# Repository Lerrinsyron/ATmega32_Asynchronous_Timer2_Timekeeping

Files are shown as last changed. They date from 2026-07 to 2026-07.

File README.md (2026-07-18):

ATmega32 Asynchronous Timer2 Timekeeping

CT 321 — Group 13 

Low-power real-time clock using ATmega32 Timer2 in asynchronous mode, driven by a 32.768 kHz watch crystal on TOSC1/TOSC2. The CPU sleeps between timer events; Timer2 keeps running and wakes the CPU exactly once per second.

Build
```bash
cd firmware

# Real hardware
avr-gcc -mmcu=atmega32 -DF_CPU=8000000UL -Os -I/usr/avr/include \
  -o hex/firmware.elf src/main.c
avr-objcopy -O ihex -R .eeprom hex/firmware.elf hex/firmware.hex

# SimulIDE
avr-gcc -mmcu=atmega32 -DF_CPU=8000000UL -DSIMULIDE_MODE -Os -I/usr/avr/include \
  -o hex/firmware_simulide.elf src/main.c
avr-objcopy -O ihex -R .eeprom hex/firmware_simulide.elf hex/firmware_simulide.hex
```

If `/usr/avr/include` doesn't exist on your machine, run `find /usr -name "io.h" | grep avr` to find your avr-libc path.

SimulIDE

Load hex/firmware_simulide.hex into the ATmega32. Set Freq to `8000000` and Serial Monitor baud to `9600`.

> ⚠️ Known limitation: SimulIDE cannot model the external 32.768 kHz crystal on TOSC1/TOSC2. The SIMULIDE_MODE   build uses an internal-clock CTC fallback to produce the same 1-second tick. The KiCad design remains correct for real hardware.

Common Issues

Garbage output on serial monitor baud rate mismatch. Confirm SimulIDE Serial Monitor is set to 9600, not 4800.

"SLEEP instruction not fully implemented" warning expected. SimulIDE does not model power-save sleep. Ignore it; everything else works correctly.

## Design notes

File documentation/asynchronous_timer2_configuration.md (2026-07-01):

# SimulIDE Simulator Limitation — Asynchronous Timer2 Oscillator

## Limitation Description

SimulIDE 1.1.0 does not fully model the external crystal oscillator circuit
connected to the TOSC1 (PC6) and TOSC2 (PC7) pins of the ATmega32. When the
`AS2` bit in the `ASSR` register is set to 1 and an external 32.768 kHz
crystal is wired to TOSC1/TOSC2, SimulIDE does not drive Timer2 from that
crystal. Timer2 either does not run or behaves incorrectly in simulation.

This is a known limitation of SimulIDE's AVR peripheral model — the
asynchronous clock domain for Timer2 is not implemented.

Additionally, SimulIDE prints the following warning when the firmware executes
a sleep instruction:

    Warning: AVR SLEEP instruction not Fully implemented
    eMcu::sleep: Sleeping

This confirms that power-save sleep mode (SLEEP_MODE_PWR_SAVE), which keeps
Timer2 running while the CPU halts, is also not fully modelled. In simulation
the CPU continues executing rather than entering a true sleep state.

---

## Impact on Simulation

| Feature | Real hardware | SimulIDE behaviour |
|---|---|---|
| Timer2 async crystal clock | Runs from 32.768 kHz TOSC | Not modelled |
| 1-second overflow interrupt | Exact, zero error | Not generated |
| Power-save sleep mode | CPU halts, Timer2 runs | CPU does not halt |
| Wake on Timer2 overflow | Works correctly | Not triggered |

---

## Workaround Implemented

As permitted by the project specification, an equivalent Timer2 configuration
using the internal CPU clock was implemented for simulation. This is activated
by compiling the firmware with the `-DSIMULIDE_MODE` preprocessor flag:

```bash
avr-gcc -mmcu=atmega32 -DF_CPU=8000000UL -DSIMULIDE_MODE -Os \
  -I/usr/avr/include \
  -o hex/firmware_simulide.elf src/main.c

avr-objcopy -O ihex -R .eeprom hex/firmware_simulide.elf firmware_simulide.hex
```

### Fallback Timer2 Configuration

In SimulIDE mode, Timer2 is configured in CTC (Clear Timer on Compare) mode
using the internal 8 MHz CPU clock:

```c
TCCR2 = (1 << WGM21)                           /* CTC mode            */
      | (1 << CS22) | (1 << CS21) | (1 << CS20); /* prescaler /1024   */
OCR2  = 77;
TIMSK |= (1 << OCIE2);   /* compare-match interrupt ~100 times/second */
```

The ISR accumulates 100 compare-match events before incrementing the clock,
producing a software-defined 1-second period with ~0.16% timing error.

### What Remains Unchanged in Simulation

All timekeeping logic, alarm comparison, LED toggling, buzzer activation,
button handling, and USART output behave identically in both the real hardware
and SimulIDE builds. Only the clock source differs.

---

## KiCad Design Correctness

Despite the simulator limitation, the KiCad schematic and PCB layout reflect
the correct real-hardware design:

- 32.768 kHz watch crystal connected between TOSC1 (PC6) and TOSC2 (PC7)
- Two 22 pF NP0/C0G load capacitors from each crystal pin to GND
- Crystal placed close to the MCU with short traces
- TOSC traces routed away from switching outputs

The SimulIDE workaround is purely a firmware compile-time switch and does not
affect the hardware design in any way.

---

## Sleep Mode Documentation

Since SimulIDE does not implement power-save sleep mode, the low-power
behaviour is documented here rather than demonstrated in simulation.

In real hardware operation:

1. After each Timer2 overflow ISR completes, `main()` calls `enter_sleep()`
2. The CPU enters SLEEP_MODE_PWR_SAVE — halting the CPU clock and most peripherals
3. Timer2 and its external crystal oscillator continue running unaffected
4. After exactly 1 second the next Timer2 overflow fires, waking the CPU
5. The ISR runs, updates the clock, and `main()` resumes briefly before sleeping again

In this mode the ATmega32 current consumption drops from ~5 mA active to
roughly 1–2 µA, allowing a coin cell battery to power the timekeeping system
for months.

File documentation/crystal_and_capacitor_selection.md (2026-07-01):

# Crystal and Load Capacitor Selection

## 32.768 kHz Watch Crystal

The ATmega32 Timer2 asynchronous oscillator requires an external low-frequency
crystal connected to TOSC1 (PC6) and TOSC2 (PC7). The standard choice for
timekeeping applications is a 32.768 kHz watch crystal.

### Why 32.768 kHz?

32.768 kHz = 2^15 Hz

This frequency is a power of two. Dividing it by 2 fifteen times gives exactly
1 Hz — one tick per second. This makes it the industry standard for all
real-time clock (RTC) applications including wristwatches, alarm clocks, and
embedded timekeeping systems.

In this project the division is handled by Timer2's prescaler and 8-bit
overflow rather than a binary divider chain, but the principle is the same.

### Selected Crystal

| Parameter | Value |
|---|---|
| Frequency | 32.768 kHz |
| Package | Cylindrical through-hole (2-pin), e.g. MC-306 or equivalent |
| Frequency tolerance | ±20 ppm typical |
| Load capacitance (CL) | 6 pF or 12.5 pF (see datasheet) |
| ESR (max) | 70 kΩ typical |
| Operating temperature | -10°C to +60°C |
| Application | TOSC1/TOSC2 on ATmega32 |

Common equivalent parts: Epson FC-135, Abracon AB38T, or any standard
32.768 kHz watch crystal with CL of 6–12.5 pF.

---

## Load Capacitors

Every crystal oscillator requires two load capacitors — one from each crystal
pin to ground. These capacitors are part of the oscillator feedback network.
Without them the crystal will not oscillate reliably or at all.

### How to Calculate Load Capacitor Value

The crystal datasheet specifies a load capacitance CL. The two external
capacitors (C1 and C2) appear in series from the oscillator's perspective,
so the formula is:

    CL = (C1 × C2) / (C1 + C2) + Cstray

Where Cstray is the parasitic capacitance of the PCB traces and MCU pins,
typically 2–5 pF.

For a symmetric design where C1 = C2 = C:

    CL = C/2 + Cstray
    C  = 2 × (CL - Cstray)

### Calculation for This Project

Assuming CL = 12.5 pF and Cstray = 2 pF:

    C = 2 × (12.5 - 2)
    C = 2 × 10.5
    C = 21 pF

The nearest standard capacitor value is **22 pF**.

For a crystal with CL = 6 pF:

    C = 2 × (6 - 2) = 8 pF → use 8.2 pF standard value

### Selected Load Capacitors

| Parameter | Value |
|---|---|
| Value | 22 pF (or 8.2 pF for CL=6 pF crystal) |
| Type | NP0 / C0G ceramic (low drift) |
| Voltage rating | 10 V or higher |
| Quantity | 2 (one per crystal pin) |
| Placement | As close as possible to TOSC1/TOSC2 pins on PCB |

NP0/C0G type capacitors are mandatory for oscillator circuits — they have
near-zero temperature coefficient, meaning their value does not drift with
temperature. X7R or Y5V types drift significantly and will cause the clock
to run fast or slow as temperature changes.

---

## PCB Placement Requirements

| Requirement | Reason |
|---|---|
| Place crystal within 5 mm of PC6/PC7 pins | Long traces add parasitic inductance and capacitance |
| Keep TOSC traces short and direct | Reduces noise pickup |
| Route TOSC traces away from switching signals (PB0, PB1, TXD) | Switching edges can couple into the high-impedance oscillator circuit |
| Do not place vias under crystal | Vias add stray capacitance |
| Connect load capacitor grounds to a local ground pour | Reduces ground impedance at oscillator frequency |

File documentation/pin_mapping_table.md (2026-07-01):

# Pin Mapping Table

## TOSC1 / TOSC2 — Asynchronous Timer2 Oscillator Pins

| Pin Name | ATmega32 Pin No. | Port / GPIO | Direction | Connected To | Description |
|---|---|---|---|---|---|
| TOSC1 | 29 | PC6 | Input | 32.768 kHz crystal pin 1 | Timer2 external oscillator input. Receives the crystal clock signal. |
| TOSC2 | 28 | PC7 | Output | 32.768 kHz crystal pin 2 | Timer2 external oscillator output. Completes the crystal feedback loop. |

## Notes

- When `AS2` bit in the `ASSR` register is set to 1, PC6 and PC7 are **disconnected from Port C** and dedicated exclusively to the Timer2 oscillator circuit. They cannot be used as general-purpose GPIO while asynchronous mode is active.
- The 32.768 kHz watch crystal must be connected directly between TOSC1 and TOSC2 with load capacitors from each pin to GND.
- TOSC1/TOSC2 traces must be kept short on the PCB and routed away from switching signals to avoid noise coupling into the oscillator.

## Full Project Pin Mapping

| ATmega32 Pin | Pin No. | Function | Direction | Connected To | Notes |
|---|---|---|---|---|---|
| PC6 / TOSC1 | 29 | Timer2 oscillator input | Input | 32.768 kHz crystal | Do not use as GPIO when AS2=1 |
| PC7 / TOSC2 | 28 | Timer2 oscillator output | Output | 32.768 kHz crystal | Do not use as GPIO when AS2=1 |
| PB0 | 1 | Wake-up LED | Output | LED + 330 Ω resistor | Toggles every 10 seconds |
| PB1 | 2 | Alarm buzzer | Output | Buzzer | Activates when alarm time is reached |
| PA0 | 40 | Reset button | Input | Push button to GND | Active LOW, internal pull-up enabled |
| PA1 | 39 | Set alarm button | Input | Push button to GND | Active LOW, internal pull-up enabled |
| PA2 | 38 | Increment button | Input | Push button to GND | Active LOW, internal pull-up enabled |
| PD1 / TXD | 15 | USART transmit | Output | Serial terminal RX | 4800 baud, 8N1 |
| VCC | 10 | Power supply | Power | 5 V rail | Main digital power |
| AVCC | 11 | Analog power supply | Power | 5 V rail | Required even without ADC use |
| GND | 11, 31 | Ground | Power | Ground | Both GND pins must be connected |
| RESET | 9 | Master reset | Input | 5 V rail via pull-up | Active LOW — held HIGH for normal operation |

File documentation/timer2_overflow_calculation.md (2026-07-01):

# Timer2 Prescaler and Overflow Period Calculation

## Overview

Timer2 in asynchronous mode is clocked directly from the 32.768 kHz watch
crystal via TOSC1. The goal is to configure Timer2 so that its overflow
interrupt fires exactly once per second, giving a 1 Hz timekeeping base.

---

## Timer2 Characteristics

| Property | Value |
|---|---|
| Timer width | 8-bit (counts 0 to 255) |
| Clock source | External 32.768 kHz crystal (AS2=1) |
| Overflow point  | After 256 counts (0xFF → 0x00) |
| Available prescalers | /1, /8, /32, /64, /128, /256, /1024 |

---

## Derivation

The timer overflow period is:

    T_overflow = (Prescaler × 256) / f_TOSC

We need T_overflow = 1 second and f_TOSC = 32768 Hz.

Rearranging for the prescaler:

    Prescaler = (T_overflow × f_TOSC) / 256
    Prescaler = (1 × 32768) / 256
    Prescaler = 128

**Prescaler = 128** is an available option (CS2[2:0] = 0b101). ✓

---

## Verification

    f_TOSC      = 32768 Hz
    Prescaler   = 128
    Timer ticks per second = 32768 / 128 = 256 ticks/second

    Timer2 is 8-bit → overflows after 256 counts

    T_overflow  = 256 / 256 = 1.000 second ✓

Timer2 generates exactly one overflow interrupt per second with zero error.
This is the key advantage of the 32.768 kHz frequency — it divides cleanly
by 128 × 256 = 32768 with no remainder.

---

## Register Configuration

```c
/* Enable asynchronous mode — Timer2 clocked from TOSC1 crystal */
ASSR |= (1 << AS2);

/* Set prescaler /128: CS22=1, CS21=0, CS20=1 */
TCCR2 = (1 << CS22) | (1 << CS20);

/* Wait for async registers to synchronise (mandatory per datasheet) */
while (ASSR & ((1 << TCN2UB) | (1 << OCR2UB) | (1 << TCR2UB)));

/* Enable Timer2 overflow interrupt */
TIMSK |= (1 << TOIE2);
```

### CS2 Prescaler Bit Table (ATmega32 Datasheet)

| CS22 | CS21 | CS20 | Prescaler |
|---|---|---|---|
| 0 | 0 | 0 | Timer stopped |
| 0 | 0 | 1 | /1 |
| 0 | 1 | 0 | /8 |
| 0 | 1 | 1 | /32 |
| 1 | 0 | 0 | /64 |
| 1 | 0 | 1 | /128 ← selected |
| 1 | 1 | 0 | /256 |
| 1 | 1 | 1 | /1024 |

---

## SimulIDE Fallback Calculation

SimulIDE cannot simulate the external 32.768 kHz crystal. In simulation,
Timer2 is reconfigured in CTC (Clear Timer on Compare) mode using the
internal 8 MHz CPU clock to approximate 1-second ticks in software.

    f_CPU       = 8,000,000 Hz
    Prescaler   = 1024
    OCR2        = 77  (compare match value)

    f_compare   = f_CPU / (Prescaler × (OCR2 + 1))
    f_compare   = 8,000,000 / (1024 × 78)
    f_compare   = 8,000,000 / 79,872
    f_compare   ≈ 100.16 Hz

The ISR accumulates 100 compare-match events in a software counter
(g_tick_count) before incrementing the clock — giving a period of:

    T_second    = 100 / 100.16 ≈ 0.9984 seconds

Error ≈ 0.16% — acceptable for simulation demonstration purposes.
This fallback is activated by compiling with -DSIMULIDE_MODE and does
not affect the real hardware configuration.

---

## Summary

| Parameter | Real hardware | SimulIDE fallback |
|---|---|---|
| Clock source | 32.768 kHz crystal | 8 MHz internal RC |
| Timer mode | Normal (overflow)  | CTC (compare match)  |
| Prescaler | /128 | /1024 |
| Overflow/compare | 256 counts | OCR2 = 77 |
| ISR rate | 1 Hz exactly | ~100 Hz |
| Software accumulator | not needed | 100 ticks = 1 second |
| Timing error | 0% | ~0.16% |

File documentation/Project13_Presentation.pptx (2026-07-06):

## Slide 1

ATmega32 MCU

8 MHz internal RC

32.768 kHz Crystal

TOSC1 / TOSC2

Power-Save Sleep

µA-level idle

Timer2 Async

1-second ISR

Bare-Metal C

AVR-GCC firmware

Project 13

Asynchronous Timer2
Low-Power Timekeeping

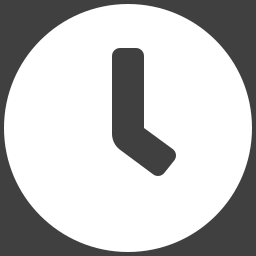
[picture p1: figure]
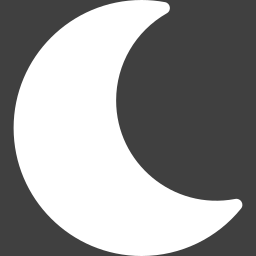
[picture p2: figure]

ATmega32 Microcontroller · 32.768 kHz Watch Crystal · Power-Save Sleep Mode

SimulIDE Simulation · KiCad Schematic & PCB · MPLAB for VS Code

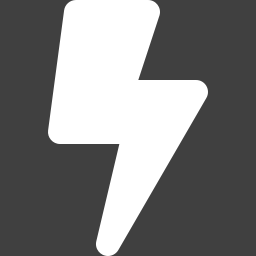
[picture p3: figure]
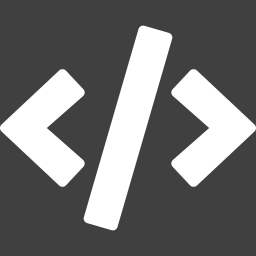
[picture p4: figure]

Embedded Systems

Computer Engineering

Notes: Introduce the project: low-power timekeeping using ATmega32 Timer2 in asynchronous mode with a 32.768 kHz watch crystal. The big idea is that Timer2 can run from its own independent clock while the CPU sleeps.

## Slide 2

The Problem & The Solution

The Problem

- Battery devices need to keep time 24/7
- CPU at 8 MHz draws 8–12 mA constantly
- Software timers drift when CPU is busy or interrupted
- Hours of battery life instead of months

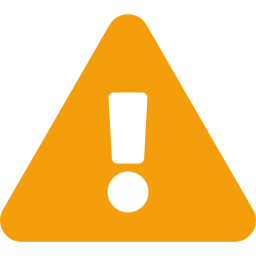
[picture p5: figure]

The Solution

- Timer2 runs from a 32.768 kHz watch crystal
- Crystal is completely independent from the CPU clock
- CPU sleeps in Power-Save mode — wakes once per second
- Average current drops to ~100 µA → months of battery life

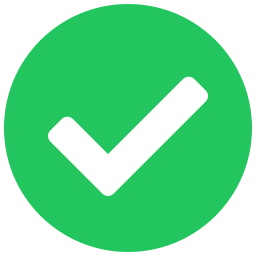
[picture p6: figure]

→

32.768 kHz crystal = 2¹⁵ Hz → divides to exactly 1 Hz with no rounding error

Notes: The core insight: every battery-powered clock needs a way to keep time while the main processor sleeps. The 32.768 kHz crystal is used because it's 2^15 Hz — binary division to exactly 1 Hz with zero rounding error. Timer2 can be wired to this crystal independently of the CPU clock.

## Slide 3

How Timer2 Async Mode Works

CPU Clock Domain

8 MHz internal RC
Drives CPU, Timer0, Timer1
Stops during Power-Save sleep

Timer2 Async Domain

32.768 kHz TOSC crystal
Runs ONLY Timer2
Never stops — even while CPU sleeps

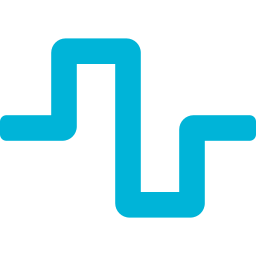
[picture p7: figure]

Power-Save Sleep

CPU halts
Synchronous clocks stop
Only async Timer2 stays alive

≠

→

Key register: ASSR |= (1 << AS2) — switches Timer2 from CPU clock to TOSC1/TOSC2 pins

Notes: Timer0 and Timer1 always use the CPU clock. Timer2 is special — setting AS2 in ASSR disconnects it from the CPU clock and connects it to whatever crystal you put on TOSC1/TOSC2 pins. This is the hardware feature at the heart of the project.

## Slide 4

System Architecture

32.768 kHz
Watch Crystal
(TOSC1/TOSC2)

async clk

Timer2
Async Mode
÷128 → 1s OVF

ISR

ATmega32 CPU
8 MHz internal RC
(Power-Save sleep)

PB0 → LED (330Ω) · Wake every 10s

PB1 → Buzzer · Alarm for 3s

Buttons (active-LOW + internal pull-ups)
PA0: Reset time · PA1: Set alarm mode · PA2: Increment field

Power-Save Sleep Cycle

PD1 → SerialTerm @ 9600 baud 8N1
TIME: HH:MM:SS · ALRM: HH:MM:SS · MODE: LOW POWER

← repeats every second (CPU active <1ms out of 1000ms)

CPU wakes
(ISR fires)

Update clock
Check alarm
Toggle LED

Set flag
Return

Main loop
Refreshes display

enter_sleep()
CPU halts

1 second
passes

→

→

→

→

→

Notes: Walk through the system architecture. Key point: the 32.768 kHz crystal feeds ONLY Timer2 via TOSC1/TOSC2 pins. The CPU wakes once per second, does its work in under a millisecond, then sleeps again. This is what makes the system low-power.

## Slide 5

Timer2 Timing Calculation

32768

Hz

= 2¹⁵

Only frequency that divides to exactly 1 Hz using binary prescalers alone

Crystal frequency

f_TOSC = 32,768 Hz

Timer2 is 8-bit → counts 0–255

256 counts per overflow

Prescaler needed

N = 32768 ÷ 256 = 128

TCCR2 bits CS2[2:0]

= 0b101 (prescaler /128)

Overflow period

T = (256 × 128) ÷ 32768 = 1.000 s ✓

Load caps C1 & C2 = 12 pF match the crystal's specified load capacitance for stable oscillation

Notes: Walk through the math. Timer2 has 256 counts before overflow. 32768 ÷ 256 = 128 exactly. So prescaler /128 gives exactly one overflow per second with no rounding error ever. The load capacitors must match the crystal's datasheet spec (typically 7-12 pF for watch crystals).

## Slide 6

KiCad Schematic & PCB Design

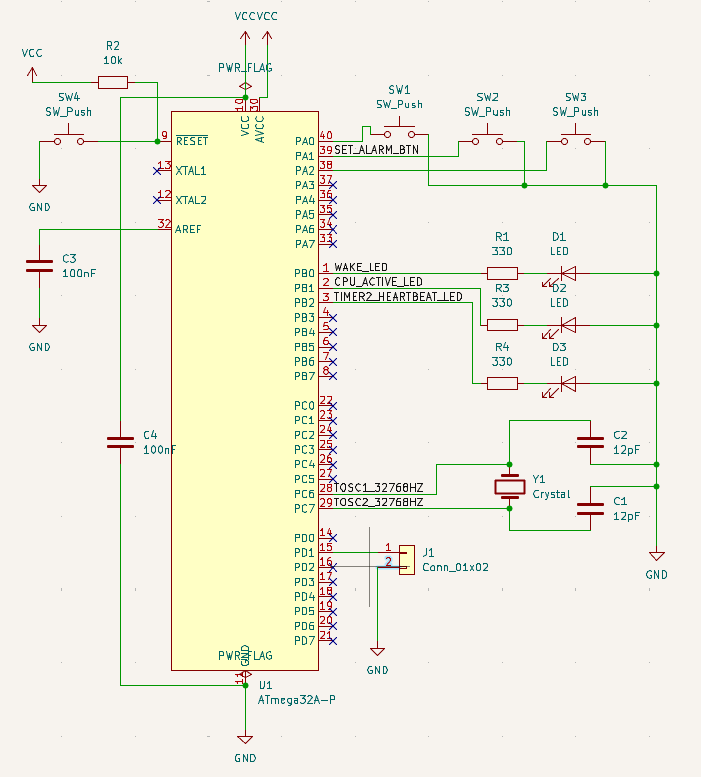
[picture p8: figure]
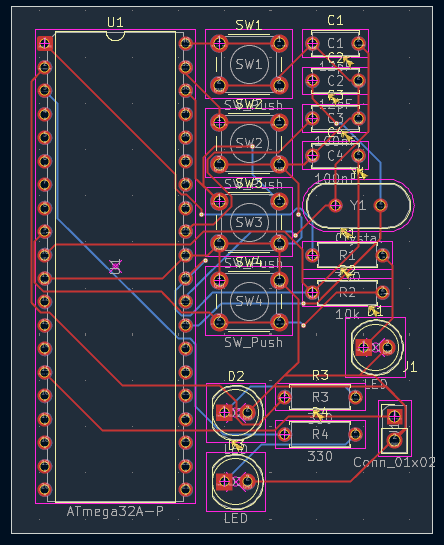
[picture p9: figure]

✔ C1 & C2 (12 pF) immediately adjacent to crystal — short GND routes

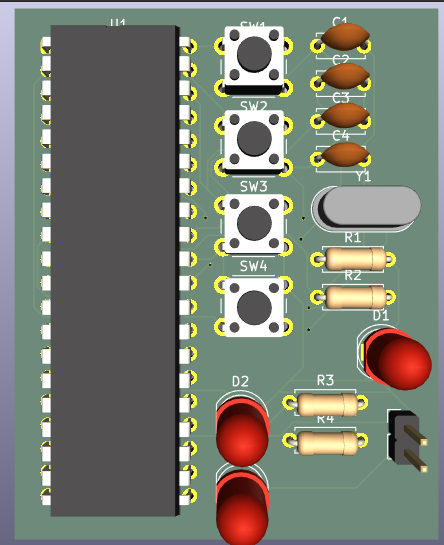
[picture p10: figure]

✔ Y1 placed as close as possible to PC6/PC7 — minimises TOSC trace length

Figure 3.1 — KiCad Schematic

✔ TOSC1/TOSC2 traces routed away from LED switching outputs

Figure 3.4 — KiCad 3D PCB Render

ERC: 0 errors · DRC: 0 violations · Gerber files generated

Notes: The schematic has all five required net labels: TOSC1_32768HZ, TOSC2_32768HZ, WAKE_LED, ALARM_BUZZER, SET_ALARM_BTN. The PCB follows the crystal placement rules: crystal close to TOSC pins, load caps adjacent, TOSC traces away from switching outputs.

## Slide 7

Firmware: The Heart — Timer2 ISR

ISR(TIMER2_OVF_vect) { g_seconds++;
// roll over at 60/60/24
if (g_seconds % 10 == 0)
PORTB ^= (1<<PB0); // toggle LED
if (time == alarm_time) {
PORTB |= (1<<PB1); // buzzer ON
g_buzz_countdown = 3;
}
g_time_updated = true;
}

Runs exactly once per second — no drift

✓

Increments seconds → minutes → hours with midnight rollover

✓

Toggles PB0 (LED) every WAKEUP_INTERVAL=10 seconds

✓

Activates buzzer (PB1) for ALARM_BUZZ_DURATION=3s on alarm match

✓

Sets g_time_updated flag — wakes main loop to refresh serial output

✓

All variables volatile — modified in ISR, read in main

!

cli()/sei() around multi-byte reads to prevent torn reads

!

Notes: The ISR is the heart of the firmware. It fires exactly once per second (on real hardware). Inside it: increment the clock, check for 10-second LED toggle, check alarm condition, manage buzzer countdown, then set the flag that wakes the main loop to print to serial.

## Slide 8

Two Critical Details

Async Register Sync (MANDATORY)

Timer2 registers cross two clock domains.
After writing, you MUST wait for ASSR busy flags to clear:

while (ASSR & (TCN2UB|OCR2UB|TCR2UB));

Skipping this loop silently corrupts
Timer2 configuration — no error, no warning, just a timer that doesn't work correctly. The ATmega32 datasheet mandates this wait.

Sleep Mode Selection

SLEEP_MODE_PWR_SAVE

Stops CPU + sync clocks.
Async Timer2 keeps running from crystal.

SLEEP_MODE_IDLE

Stops only CPU.
Keeps sync clocks — needed for CTC fallback.

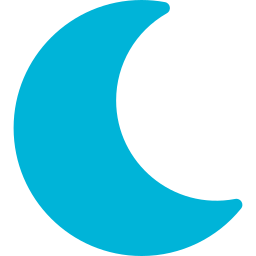
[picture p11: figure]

Real hardware

SimulIDE fallback

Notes: Two non-obvious implementation details. First: the ASSR busy flags MUST be waited on after any Timer2 register write — skipping this is a silent bug. Second: Power-Save stops the synchronous clock, which is perfect for the real hardware path but breaks the SimulIDE fallback that uses the synchronous clock for Timer2.

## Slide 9

SimulIDE: Limitation & Fallback Solution

SimulIDE Cannot Model TOSC

Without SIMULIDE_MODE flag:
• Timer2 waits for crystal that never starts
• ASSR busy flags never clear
• enter_sleep() → CPU parks permanently
• Serial output stops after one line

SIMULIDE_MODE Fallback

Compile with: make simulide
• Timer2 → CTC mode, internal 8 MHz clock
• OCR2=77, /1024 → ~100 ticks/second
• ISR accumulates 100 ticks = 1 second
• SLEEP_MODE_IDLE keeps sync clock alive

What's different vs. what stays the same

Timer2 clock source

Real Hardware

32.768 kHz TOSC crystal

SimulIDE Fallback

8 MHz internal CPU clock

Timer2 mode

Normal (overflow)

CTC (compare match)

Sleep mode

All application logic (clock/alarm/LED/buzzer/USART/buttons)

SLEEP_MODE_PWR_SAVE

✓ IDENTICAL

SLEEP_MODE_IDLE

✓ IDENTICAL

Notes: Two separate bugs that had to be understood and fixed for the SimulIDE simulation to work. The firmware has two compile-time paths. Everything the user sees — clock counting, alarm, LED, buzzer, buttons — is identical. Only the clock source and sleep depth change.

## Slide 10

Simulation Results

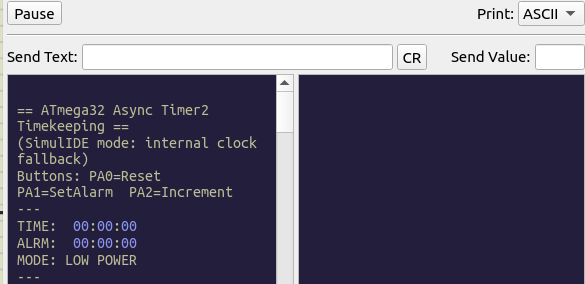
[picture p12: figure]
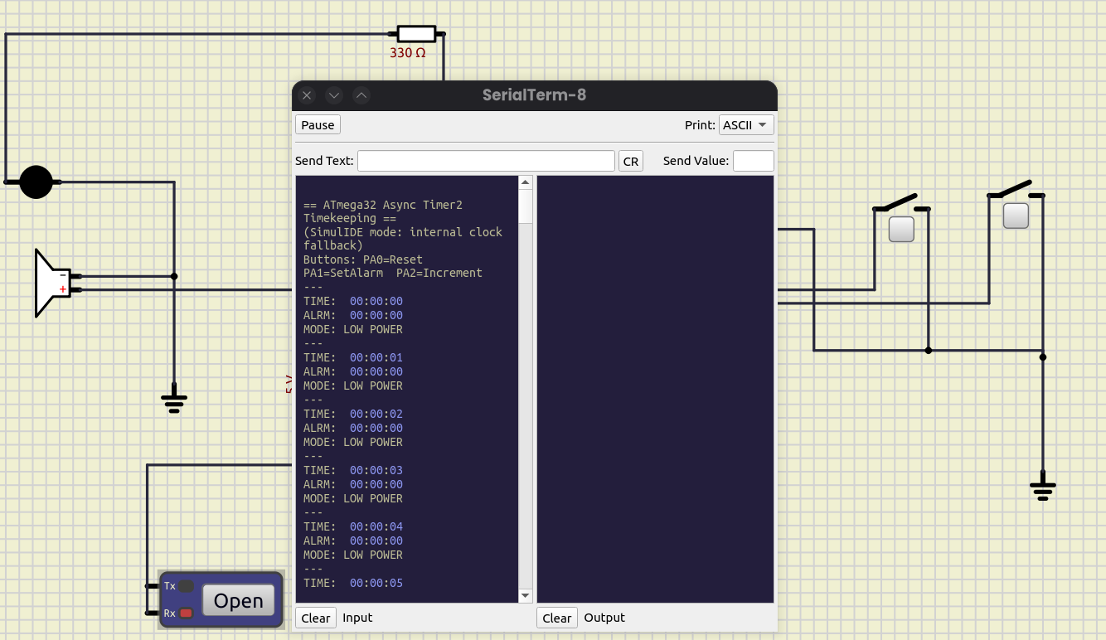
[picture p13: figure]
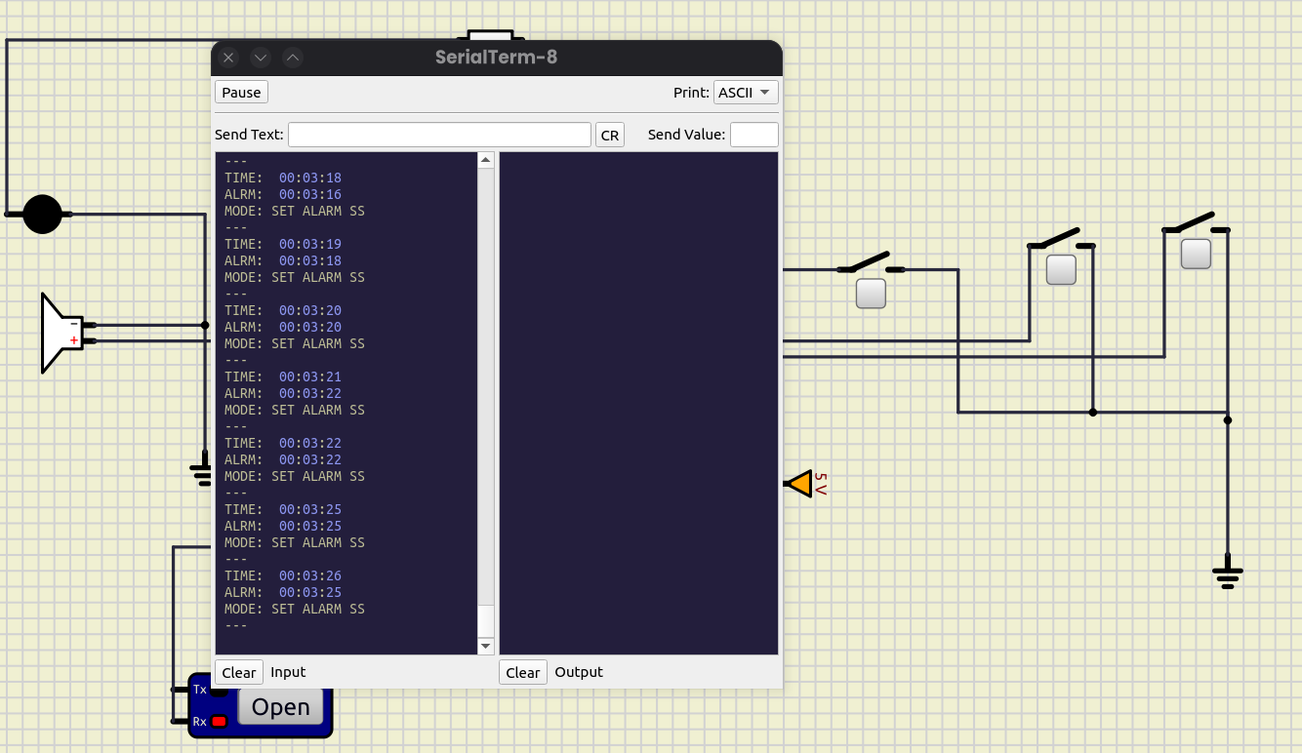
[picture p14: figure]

TC-04: SET ALARM mode

Alarm set and buzzer fires

TC-01: Boot + 00:00:00

System initialises correctly

TC-02: Seconds increment

Timer2 counting in real time

✓ PASS

TC-01
Boot / Reset

✓ PASS

TC-02
Clock counts

✓ PASS

TC-03
LED heartbeat

✓ PASS

TC-04
Alarm / buzzer

✓ PASS

TC-05
Reset button

✓ PASS

TC-06
Sleep (docs)

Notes: All six test cases passed. TC-06 is documented rather than a traditional pass/fail since SimulIDE doesn't fully model sleep modes — the workaround (SLEEP_MODE_IDLE in simulation) is explained and justified.

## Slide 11

Key Learning Outcomes

Async Peripheral Operation

Timer2 is unique among ATmega32 timers — only it can be decoupled from the CPU clock via TOSC pins. This decoupling enables hardware timekeeping independent of CPU state.

01

Clock Domain Crossing

Registers that cross clock domains require explicit synchronisation. The ASSR busy-flag wait loop is mandatory; skipping it produces a silent, hard-to-diagnose bug.

02

Sleep Mode Mechanics

SLEEP_MODE_PWR_SAVE stops all synchronous clocks but preserves the async Timer2 domain. Pairing it with a synchronous-clocked Timer2 (fallback) creates a deadlock — the correct fix is SLEEP_MODE_IDLE.

03

USART Baud Rate Sensitivity

UBRR is computed from F_CPU. A MCU clock mismatch between firmware and simulator (16 MHz vs 8 MHz) garbles every byte. Matching both values is the first debug step for garbled serial.

04

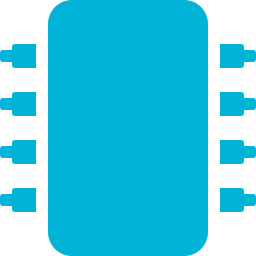
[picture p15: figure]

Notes: Four takeaways from the project. Most important: Timer2's unique async capability is the enabler for everything else. The register sync and sleep mode mechanics are the two 'gotchas' that separate a working implementation from a subtly broken one.

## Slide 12

EXTENSION TASK

Periodic Sensor Logging

Extend the base system: wake every N seconds → read ADC sensor → log to EEPROM → sleep again

Power-Save
Sleep

Timer2
Overflow

Normal ISR
(clock/alarm)

Every 60s:
g_log_pending

ADC read
(sensor value)

Write to
EEPROM

Back to
Sleep

→

→

→

→

→

→

EEPROM Log Record (10 bytes)

Hours (0–23)

Minutes (0–59)

Seconds (0–59)

ADC value (0–1023, 10-bit)

Reserved / checksum

Power Budget (60s log interval)

≈ 10,000 hours (1 yr+) on a 1000 mAh battery

Offset 0

Power-Save sleep

~59.9 s / min

~16 µA

Offset 1

Offset 2

ISR (1s × 60)

ADC + USART log

~50 µs × 60

~5 ms

~8 mA (brief)

~12 mA

Offset 3–4

EEPROM write

~3.4 ms

~5 mA

Offset 5–9

Average current

whole minute

~100 µA

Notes: Optional extension task. The base system already has the infrastructure: Timer2 fires every second. Adding a log_countdown counter means every 60 seconds you enable the ADC, read a sensor, write 10 bytes to EEPROM, and go back to sleep. The power impact is minimal.

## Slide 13

Project Complete

Asynchronous Timer2
Low-Power Timekeeping

KiCad Schematic

Crystal on TOSC1/TOSC2
All net labels present
ERC: 0 errors

Firmware (C)

Async Timer2 ISR
Power-Save sleep
SimulIDE fallback

SimulIDE Verified

6/6 test cases PASS
Bug root-causes documented
Fallback path working

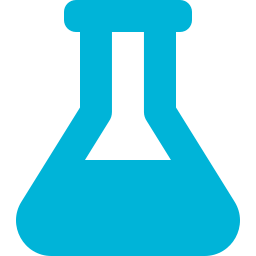
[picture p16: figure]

KiCad PCB

Crystal near TOSC pins
Noise separation
DRC: 0 violations

GitHub: ATmega32_Asynchronous_Timer2_Timekeeping · [ insert repository URL ]

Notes: Closing slide. Summarise the four deliverables. The project demonstrates a complete embedded systems design cycle: concept → schematic → PCB → firmware → simulation → documentation. The GitHub repository link goes here.

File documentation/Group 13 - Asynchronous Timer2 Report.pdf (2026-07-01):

THE UNIVERSITY OF DODOMA.

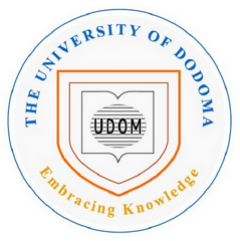
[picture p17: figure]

COLLEGE OF INFORMATICS AND VIRTUAL EDUCATION. GROUP 13 PROJECT REPORT.

## Asynchronous Timer2 Low-PowerTimekeeping System

MEMBERS.

NAME | REGISTRATION | COURSE
OLARIVU THADAYO | T23-03-18979 | Bsc. CE3
FRANK JULIUS | T23-03-12976 | Bsc. CE3
NKIYA MANDA | T22-03-08714 | Bsc. CE4
KELVIN ASSENGA | T22-03-11783 | Bsc. CE3

## Abstract

This report documents the design and implementation of a low-power real-time timekeeping system using the ATmega32 microcontroller. The central objective is to demonstrate the asynchronous operation of Timer/Counter2 driven by an external 32.768 kHz watch crystal connected to the dedicated TOSC1 and TOSC2 oscillator pins (PC6 and PC7). By operating Timer2 from a separate low-frequency clock domain, the system achieves one-second timekeeping interrupts while the main CPU spends the majority of its time in Power-Save sleep mode, halting all activity except the asynchronous timer — a design pattern fundamental to battery-operated embedded devices such as alarm clocks, data loggers, and wearable sensors.

The system maintains a real-time clock (HH:MM:SS), drives a periodic wake-up LED on PB0 at ten-second intervals, activates a buzzer on PB1 when a user-programmed alarm time is reached, and accepts user input through three push buttons for time reset, alarm setting, and field increment. Current time and alarm state are transmitted over USART to a serial terminal at 9600 baud. A hardware schematic and PCB layout were designed in KiCad, firmware was developed in MPLAB for VS Code using bare-metal C targeting the AVR architecture, and the system was verified in SimulIDE using an internal-clock fallback path because SimulIDE does not model the external TOSC oscillator circuit.

Keywords: ATmega32, asynchronous Timer2, TOSC1, TOSC2, 32.768 kHz crystal, real-time clock, low-power design, Power-Save mode, embedded timekeeping, alarm system, AVR.

## Table of Contents

Front Matter
- Title Page
- Abstract
- Table of Contents

Chapter One: Introduction
- 1.1 Background
- 1.2 Problem Statement
- 1.3 Proposed Solution
- 1.4 Project Objectives
- 1.5 Scope and Limitations
- 1.6 Report Organization

Chapter Two: System Design
- 2.1 System Overview and Block Diagram
- 2.2 Pin Mapping and Connection Strategy
- 2.3 Component Selection and Bill of Materials
- 2.4 Timer2 Asynchronous Clock Configuration and Timing Calculations
- 2.5 Power Supply and Decoupling Strategy
- 2.6 Design Trade-offs and Justifications

Chapter Three: Hardware Implementation (KiCad)
- 3.1 Schematic Design
- 3.2 Electrical Rules Check (ERC)
- 3.3 PCB Layout Design
- 3.4 Design Rules Check (DRC)
- 3.5 Output Generation (Gerber Files and BOM)

Chapter Four: Firmware Implementation
- 4.1 Overview and Development Environment
- 4.2 Firmware Architecture
- 4.3 Timer2 Asynchronous Configuration
- 4.4 Timekeeping and Alarm Logic (ISR)

- 4.5 Button Handling and Debouncing
- 4.6 Serial Output (USART)
- 4.7 Sleep Mode and Wake-Up Strategy
- 4.8 SimulIDE Fallback Mode
- 4.9 GitHub Repository Reference

Chapter Five: Simulation and Testing
- 5.1 Simulation Environment
- 5.2 Firmware Loading and Configuration
- 5.3 Test Cases and Results

Chapter Six: Conclusion
- 6.1 Project Summary
- 6.2 Learning Outcomes and Discussion
- 6.3 Future Work

## Chapter One

## Introduction

### 1.1 Background

A fundamental requirement of embedded systems across many application domains — including consumer electronics, industrial monitoring, healthcare devices, and environmental sensing — is the ability to maintain accurate time while consuming as little power as possible. Digital wristwatches, alarm clocks, data loggers, and attendance systems all depend on a time base that continues to run accurately even when the main processor is dormant.

The ATmega32 microcontroller addresses this requirement through a dedicated feature of its Timer/Counter2 peripheral: asynchronous operation. Unlike Timer0 and Timer1, which are always driven by the main system clock, Timer2 can be switched to an entirely separate clock domain by setting the AS2 bit in the ASSR register. When this mode is active, Timer2 is clocked from an external oscillator crystal connected to two dedicated pins — TOSC1 (PC6) and TOSC2 (PC7) — completely independently of whatever clock source the CPU is using.

The standard crystal for this purpose is the 32.768 kHz watch crystal, a component found in virtually every battery-powered timekeeping device. Its frequency is 2^15 Hz, which means it divides down to exactly 1 Hz through purely binary counting — no rounding error, no frequency drift from prescaler mismatch. With the correct Timer2 prescaler setting, the hardware generates one interrupt per second with no software overhead required for the time base itself.

This project introduces students to asynchronous timer operation, real-time clock design, low-power sleep strategies, alarm logic, user input handling, and serial output — a comprehensive introduction to practical embedded system design around a single, elegant hardware feature.

### 1.2 Problem Statement

Embedded systems deployed in power-constrained environments — battery-operated clocks, remote sensors, attendance terminals — cannot afford to keep the CPU active continuously just to increment a time counter. A microcontroller running at 8 MHz with its full peripheral set active draws tens of milliamperes; on a small battery, this translates to hours of operation instead of months or years.

Furthermore, timekeeping based on software loops tied to the main system clock is fragile: any interrupt latency, any time spent in non-timekeeping code, or any change to the CPU frequency corrupts the time base. A hardware timer driven by a dedicated, independent crystal eliminates all of these failure modes simultaneously.

The challenge, therefore, is to design a system that maintains accurate time 24 hours a day while keeping the CPU asleep as much as possible, waking only when something requires attention — a new second has elapsed, a button has been pressed, or an alarm condition has been reached.

### 1.3 Proposed Solution

This project implements a low-power timekeeping and alarm system using the ATmega32's asynchronous Timer2 capability. A 32.768 kHz watch crystal drives Timer2 through the TOSC1/TOSC2 pins, with the prescaler set to /128, producing one Timer2 overflow interrupt every exactly 1 second. The CPU spends almost all of its time in Power-Save sleep mode, which halts the CPU and all synchronous peripherals while keeping the asynchronous Timer2 domain fully active.

Each Timer2 overflow interrupt wakes the CPU for a few microseconds to increment the clock variables, check the alarm condition, toggle the wake-up LED at ten-second intervals, control the buzzer, and set a flag for the main loop to refresh the serial terminal display. The CPU then returns to sleep until the next second interrupt. Three push buttons allow the user to reset the clock to 00:00:00, enter alarm-setting mode, and increment the selected alarm field.

### 1.4 Project Objectives

The primary objectives of this project are as follows:

- To configure Timer2 in asynchronous mode using an external 32.768 kHz watch crystal on TOSC1 and TOSC2, producing one overflow interrupt per second.
- To implement a real-time software clock (hours, minutes, seconds) maintained entirely within the Timer2 overflow ISR.
- To implement a user-programmable alarm that activates a buzzer for a configurable duration when the current time matches the alarm time.
- To implement a periodic wake-up LED that toggles every ten seconds as a visible heartbeat indicator.

- To implement low-power operation using Power-Save sleep mode, with the CPU waking only on Timer2 overflow.
- To handle user input from three buttons with software debouncing: PA0 (reset), PA1 (set alarm mode), and PA2 (increment).
- To transmit the current time, alarm time, and operating mode to a serial terminal via USART at 9600 baud every second.
- To design the complete circuit schematic and PCB layout in KiCad, following the oscillator placement and noise-separation requirements of the project specification.
- To verify the system in SimulIDE, documenting the simulator limitation regarding TOSC oscillator modelling and demonstrating the equivalent internal-clock fallback.
- To organise all project artefacts in a structured GitHub repository with meaningful commit history.

### 1.5 Scope and Limitations

Scope:
- Timekeeping resolution of one second, maintained in hardware by Timer2 asynchronous overflow.
- Alarm functionality with buzzer activation for a configurable duration (default 3 seconds).
- Wake-up LED toggle at every ten-second mark as a low-power heartbeat indicator.
- Serial terminal output over USART at 9600 baud, 8N1.
- Software button debouncing with a 20 ms delay-and-confirm strategy.
- SimulIDE-based verification using an internal-clock CTC fallback path for Timer2.

Limitations:
- SimulIDE does not model the external 32.768 kHz TOSC oscillator circuit. The simulator fallback uses an internal-clock CTC configuration on Timer2 with SLEEP_MODE_IDLE to demonstrate identical logic. This limitation is documented in the firmware header and in Chapter 5.
- The system does not include a battery backup for the clock registers; time is lost on power cycle.
- No display other than the USART serial terminal is implemented; an LCD or 7-segment display would require additional GPIO.
- The buzzer is driven directly from PB1 without a transistor or MOSFET driver; this is acceptable for a simulation buzzer model but a real piezo buzzer at higher current would require a driver stage.
- Physical hardware prototype and oscilloscope verification are outside the scope of this report; all verification is simulation-based.

### 1.6 Report Organization

The remainder of this report is structured as follows:

- Section 2: System Design presents the block diagram, pin mapping, bill of materials, Timer2 timing calculations, and power strategy.
- Section 3: Hardware Implementation describes the KiCad schematic, ERC, PCB layout, DRC, and Gerber file generation.
- Section 4: Firmware Implementation explains the asynchronous timer configuration, ISR logic, sleep strategy, button handling, USART output, and SimulIDE fallback.
- Section 5: Simulation and Testing documents the SimulIDE setup, firmware loading, and all test case results.
- Section 6: Conclusion summarises outcomes, learning points, and suggested future extensions.

## Chapter Two: System Design

### 2.1 System Overview and Block Diagram

The system is organized into six functional blocks that form a pipeline from the external time reference through to user-visible outputs:

- Clock Source Block — 32.768 kHz watch crystal on TOSC1/TOSC2, providing an independent asynchronous clock to Timer2.
- Timer Block — ATmega32 Timer2 in asynchronous overflow mode; overflows every 1 second and fires the timekeeping ISR.
- Control Block — ATmega32 CPU running at 8 MHz internal RC, spending most time in Power-Save sleep; wakes on Timer2 overflow.
- Output Block — PB0 (wake-up LED via 330 Ω resistor) and PB1 (buzzer) driven directly from the ISR and main loop logic.
- User Input Block — Three active-LOW push buttons on PA0 (reset), PA1 (set alarm), and PA2 (increment), read with software debouncing.
- Communication Block — USART TX on PD1 at 9600 baud, 8N1, streaming current time and mode to a serial terminal.

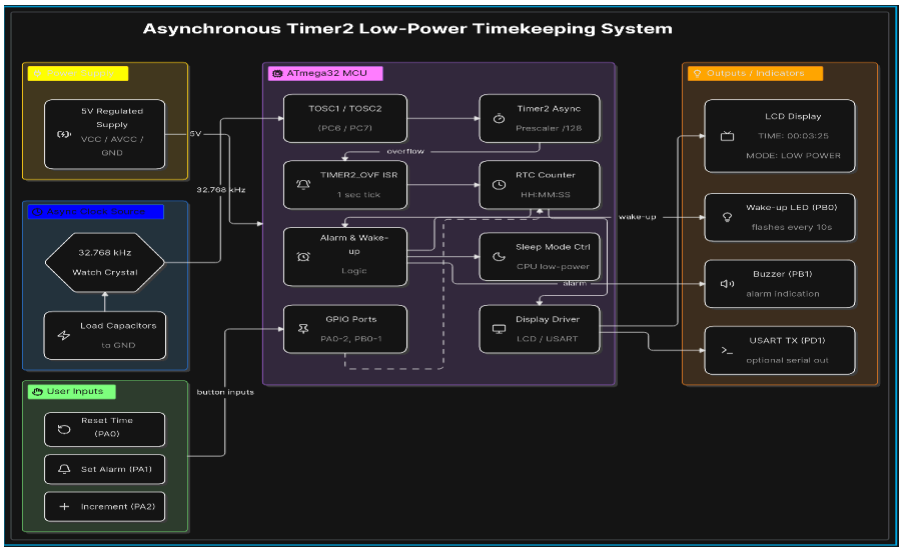
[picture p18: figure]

Figure 2.1 — High-level system block diagram showing data flow from crystal to CPU to outputs

### 2.2 Pin Mapping and Connection Strategy

### 2.2.1 ATmega32 Pin Allocation

Table 2.1 provides the complete pin mapping between the ATmega32 and all connected devices.

ATmega32 Pin | Pin Name / Signal | Directi on | Connected Device | Function
PC6 (Pin 28) | TOSC1 | Input | 32.768 kHz Crystal | Timer2 async clock input
PC7 (Pin 29) | TOSC2 | Output | 32.768 kHz Crystal | Timer2 async oscillator return
PB0 (Pin 1) | GPIO | Output | LED via 330 Ω | Periodic wake-up LED
PB1 (Pin 2) | GPIO | Output | Buzzer | Alarm buzzer output
PA0 (Pin 40) | GPIO | Input | Push button SW1 | Reset clock to 00:00:00
PA1 (Pin 39) | GPIO | Input | Push button SW2 | Cycle alarm-set mode
PA2 (Pin 38) | GPIO | Input | Push button SW3 | Increment selected alarm field
PD1 (Pin 15) | TXD | Output | Serial terminal | USART TX, 9600 baud, 8N1
Pin 9 (RST) | RESET | Input | SW4 + 10 kΩ pull-up | Hardware microcontroller reset
Pin 10 | VCC | Power | +5 V supply | Digital power
Pin 30 | AVCC | Power | +5 V supply | Analog power domain
Pin 32 | AREF | Input | 100 nF to GND | ADC reference decoupling
Pins 11, 31 | GND | Power | 0 V reference | Ground
Table 2.1 — Complete ATmega32 pin allocation

### 2.3 Component Selection and Bill of Materials

Table 2.2 lists all hardware components required to build the system.

Ite m | Component | Qt y | Value / Model | Purpose | Notes
1 | ATmega32 MCU | 1 | ATmega32 A-PU | Main microcontroller | 40-pin DIP
2 | Watch crystal | 1 | 32.768 kHz | Timer2 async source | TOSC1/TO SC2
3 | Load capacitor | 2 | 12 pF ceramic | Crystal oscillator support | C1, C2
4 | Decoupling cap | 2 | 100 nF ceramic | Power filtering | C3 (AREF), C4 (VCC/AVC C)
5 | LED | 1 | 5 mm any colour | Wake-up indicator | PB0 via R1
6 | Current-limit R | 1 | 330 Ω | LED protection | R1
7 | Pull-up resistor | 1 | 10 kΩ | RESET pin pull-up | R2
8 | Buzzer | 1 | Passive piezo | Alarm output | PB1
9 | Push button | 4 | Tactile SPST | User input + HW reset | SW1–SW4
10 | Serial connector | 1 | 2-pin header | USART TX access | J1
11 | 5 V power supply | 1 | USB or adapter | System power | ≥ 100 mA

Table 2.2 — Bill of Materials (BOM)

### 2.4 Timer2 Asynchronous Clock Configuration and Timing Calculations

### 2.4.1 External Crystal Frequency

The 32.768 kHz watch crystal was selected for three reasons: (1) it is the standard frequency used in all wristwatch and RTC ICs; (2) its frequency equals 2^15, which means it divides down to exactly 1 Hz through purely binary prescaling — no remainder, no accumulated error; and (3) its low frequency means it draws minimal current from the crystal oscillator circuit, contributing to the low-power design goal.

### 2.4.2 Prescaler and Overflow Period Calculation

Timer2 is an 8-bit timer, meaning it counts from 0 to 255 (256 counts per cycle) before overflowing and resetting. The required prescaler value is derived as follows:

f_TOSC = 32,768 Hz
Target = 1 overflow per second

Prescaler N such that: (256 × N) / 32768 = 1 second

N = 32768 / 256 = 128

Verification: T_overflow = (256 × 128) / 32768 = 32768 / 32768 = 1.000 second ✓

The prescaler /128 corresponds to the CS2[2:0] = 0b101 setting in TCCR2. This configuration produces one Timer2 overflow interrupt every exactly 1 second, with zero software accumulation required.

### 2.4.3 Asynchronous Register Update Synchronisation

Writing to Timer2 registers (TCNT2, OCR2, TCCR2) while AS2 is set requires waiting for the asynchronous domain to latch the new values. The ASSR register provides busy flags (TCN2UB, OCR2UB, TCR2UB) that must all clear before the CPU continues. Failing to wait can corrupt the register values. The firmware's timer2_init() function implements this mandatory wait loop as required by the ATmega32 datasheet.

Register | Value | Effect
ASSR | AS2 = 1 | Select external TOSC oscillator for Timer2
TCNT2 | 0x00 | Clear timer counter before starting
TCCR2 | CS22 | CS20 (= 0b00000101) | Prescaler /128; normal (overflow) mode
TIMSK | TOIE2 = 1 | Enable Timer2 overflow interrupt

Table 2.3 — Timer2 asynchronous register configuration

### 2.5 Power Supply and Decoupling Strategy

All logic runs from a single 5 V supply. The ATmega32 draws approximately 8–12 mA at 8 MHz in active mode but drops to roughly 1 µA (CPU halted) plus ~15 µA (Timer2 async oscillator active) during Power-Save sleep. The average current is therefore dominated by the brief 1-second active windows and the asynchronous oscillator, making the overall system suitable for coin-cell or small AAA battery operation on real hardware.

Cap acito r | Value | Placement | Purpose
C1 | 12 pF | TOSC1 pin to GND | Crystal load capacitor
C2 | 12 pF | TOSC2 pin to GND | Crystal load capacitor
C3 | 100 nF | AREF pin to GND (close) | ADC reference decoupling
C4 | 100 nF | VCC/AVCC pins to GND | High-frequency power bypass
Table 2.4 — Decoupling and oscillator load capacitor placement

### 2.6 Design Trade-offs and Justifications

Decision | Alternative Considered | Rationale for Selected Approach
32.768 kHz external crystal on TOSC1/TOSC2 | Software counter on main 8 MHz timer | Hardware timer is immune to interrupt latency; delivers exactly 1 s with no drift. Software counters accumulate error over hours.
Power-Save sleep mode | Idle or no sleep | Power-Save keeps only Timer2 async and USART active; CPU and all synchronous clocks halt. Lowest power compatible with 1-second wake cycles.
Active-LOW buttons with internal pull-ups | External pull-down resistors | Internal pull-ups eliminate four external resistors; active-LOW is the standard for ATmega I/O ports.
Software debounce (20 ms delay + re-read) | Hardware RC filter per button | Simpler circuit; 20 ms delay is imperceptible to users and adequate for mechanical switches.
USART serial terminal output | LCD or 7-segment display | Saves GPIO; any terminal program can display formatted text. Extension to LCD is straightforward by adding rows to update_display().
330 Ω LED resistor on 5 V | 220 Ω or 470 Ω | 330 Ω gives ~8.5 mA — clearly visible yet well within PB0 pin source current limit of 40 mA.
8 MHz internal RC oscillator for CPU | External crystal on XTAL1/XTAL2 | Frees the crystal pins; UBRR = 51 at 9600 baud gives < 0.2 % baud error at 8 MHz. Accurate USART timing verified in simulation.

Table 2.5 — Key design decisions and justifications

## Chapter Three

## Hardware Implementation (KiCad Schematic and PCB Layout)

This chapter documents the complete hardware design of the asynchronous Timer2 timekeeping system as implemented in KiCad EDA software. The schematic defines all electrical connections, and the PCB layout translates those connections into a manufacturable board with specific attention to crystal placement and noise separation as required by the project specification.

### 3.1 Schematic Design

### 3.1.1 Schematic Organisation

The schematic is logically divided into the following subsystems:

- Crystal Oscillator Subsystem — Y1 (32.768 kHz) with C1 and C2 (12 pF) connected between TOSC1 (PC6) and TOSC2 (PC7), with net labels TOSC1_32768HZ and TOSC2_32768HZ.
- Microcontroller Subsystem — ATmega32A-P with VCC, AVCC, GND, AREF, RESET, and oscillator connections.
- Reset Circuit — SW4 (tactile) connecting RESET to GND; R2 (10 kΩ) pulling
RESET to VCC.
- Output Subsystem — D1 (LED) via R1 (330 Ω) on PB0 (net: WAKE_LED); BZ1 (buzzer) on PB1 (net: ALARM_BUZZER).
- Button Subsystem — SW1 (SET_ALARM_BTN on PA1), SW2 (on PA2, increment), SW3 (on PA0, reset clock), each wired with internal pull-ups enabled in firmware.
- Serial Output Subsystem — J1 (2-pin header) connected to PD1/TXD.
- Power Decoupling — C3 and C4 (100 nF) placed on AREF and VCC/AVCC respectively, with PWR_FLAG symbols on VCC and GND rails.

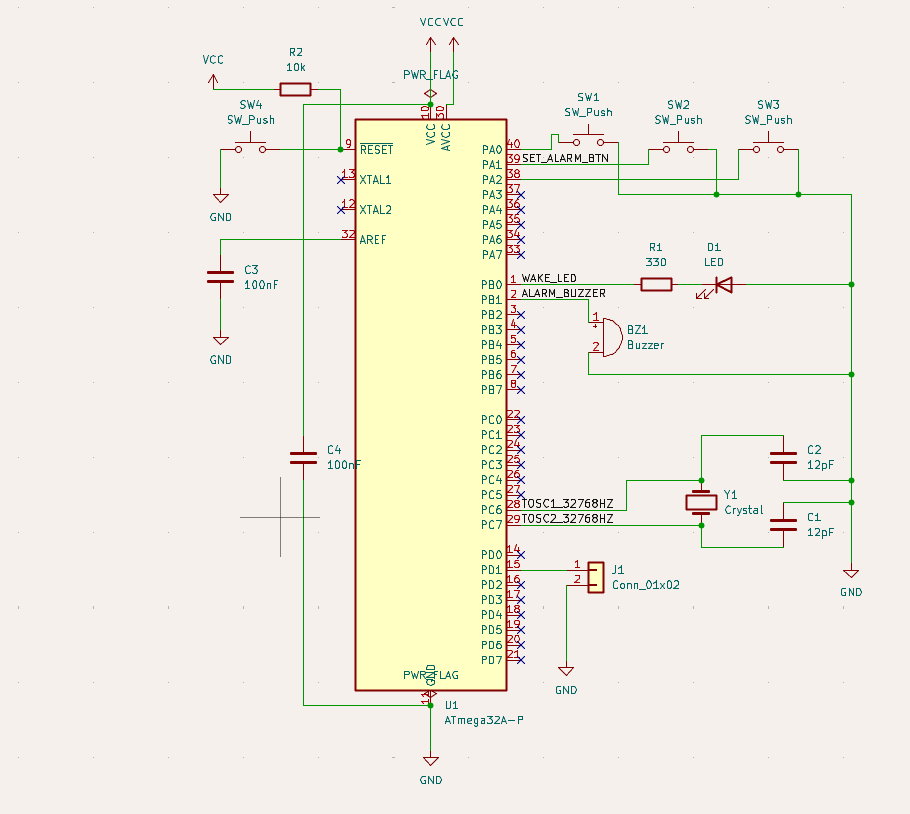
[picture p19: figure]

Figure 3.1 — Full system schematic as designed in KiCad Eeschema

### 3.1.2 Net Labels Used

Net Label | Signal | Source Pin | Destination
TOSC1_32768HZ | Timer2 async clock input | PC6 (Pin 28) | Y1 crystal pin 1
TOSC2_32768HZ | Timer2 async oscillator | PC7 (Pin 29) | Y1 crystal pin 2
WAKE_LED | Wake-up LED drive | PB0 (Pin 1) | R1 → D1 anode
ALARM_BUZZER | Buzzer drive | PB1 (Pin 2) | BZ1 positive terminal
SET_ALARM_BTN | Set alarm button | PA1 (Pin 39) | SW1 lower terminal

Table 3.1 — Required net labels as specified in the project brief

### 3.2 Electrical Rules Check (ERC)

After completing the schematic, KiCad's Electrical Rules Check (ERC) was performed to identify electrical connectivity errors such as unconnected pins, conflicting drivers, or missing power symbols.

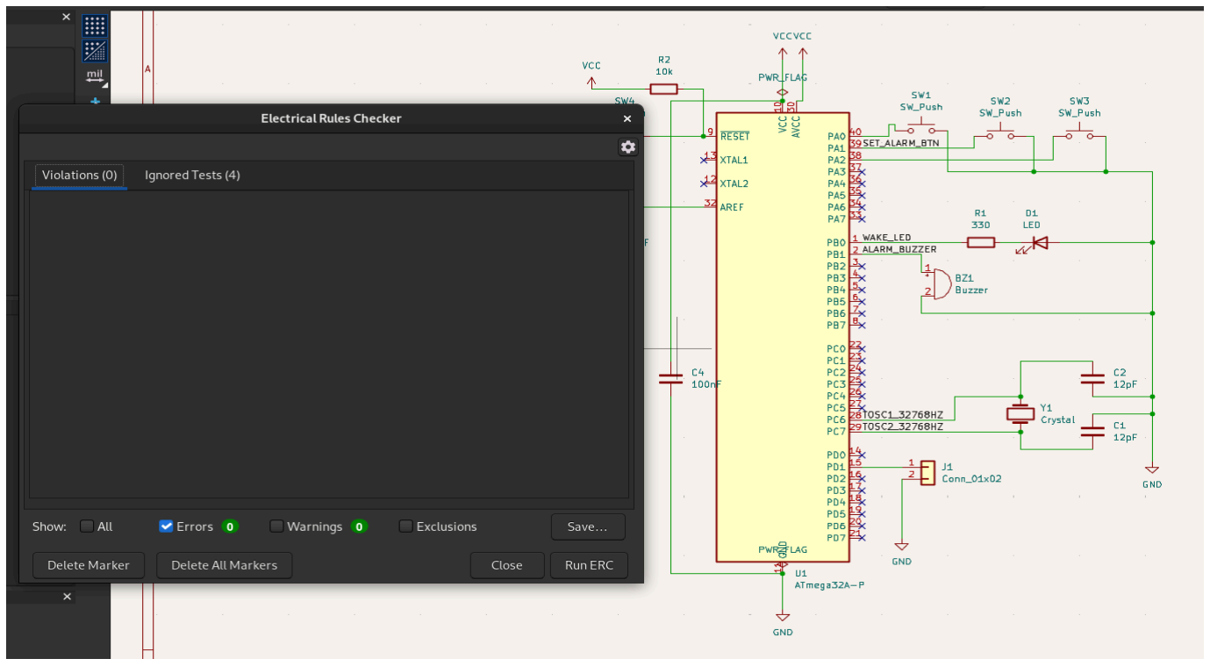
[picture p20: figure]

Figure 3.2 — ERC results confirming no electrical errors in the schematic

### 3.3 PCB Layout Design

The schematic was imported into KiCad PCB layout (Pcbnew) and all components were placed and routed. Key placement decisions were guided by the project specification's oscillator design requirements:

- Y1 (32.768 kHz crystal) was placed as close as physically possible to the PC6/PC7 pins of the ATmega32, minimising trace length on the TOSC1 and TOSC2 nets.
- C1 and C2 (12 pF load capacitors) were placed immediately adjacent to Y1, with short, direct routes to the GND plane.
- The TOSC1/TOSC2 traces were kept short and routed away from PB0, PB1, and any other switching output lines to minimise capacitive coupling and oscillator start-up degradation.
- BZ1 and D1 were placed in an accessible user-facing area. Buzzer and LED drive traces were routed on the opposite side of the board from the crystal to enforce physical noise separation.
- Buttons SW1–SW4 were placed along one edge for easy user access.
- J1 (serial header) was placed on the board edge for simple cable connection.

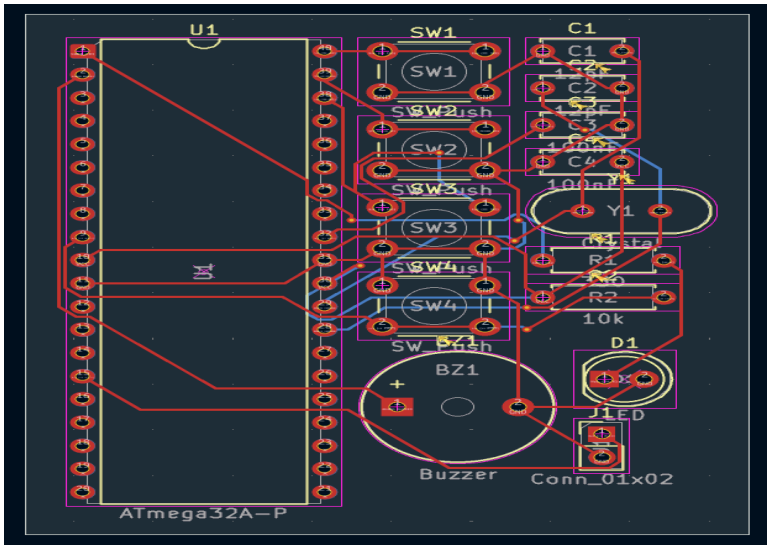
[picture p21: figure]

Figure 3.3 — PCB layout showing component placement and copper routing

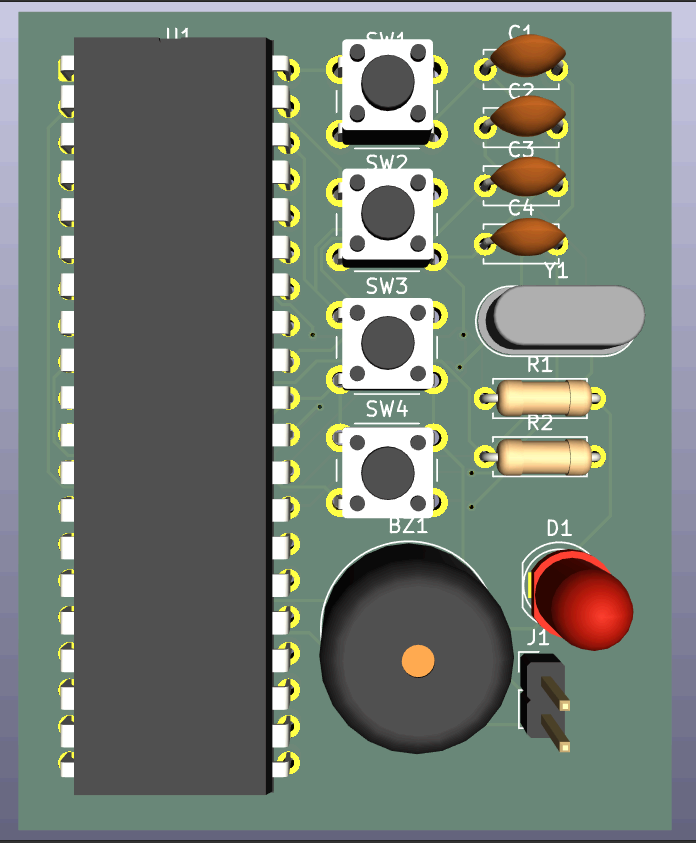
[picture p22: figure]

Figure 3.4 — KiCad 3D render of the completed PCB

### 3.4 Design Rules Check (DRC)

After completing the routing, KiCad's Design Rules Check (DRC) was run to verify that all traces, clearances, and footprint placements comply with the design rules specified for the board.

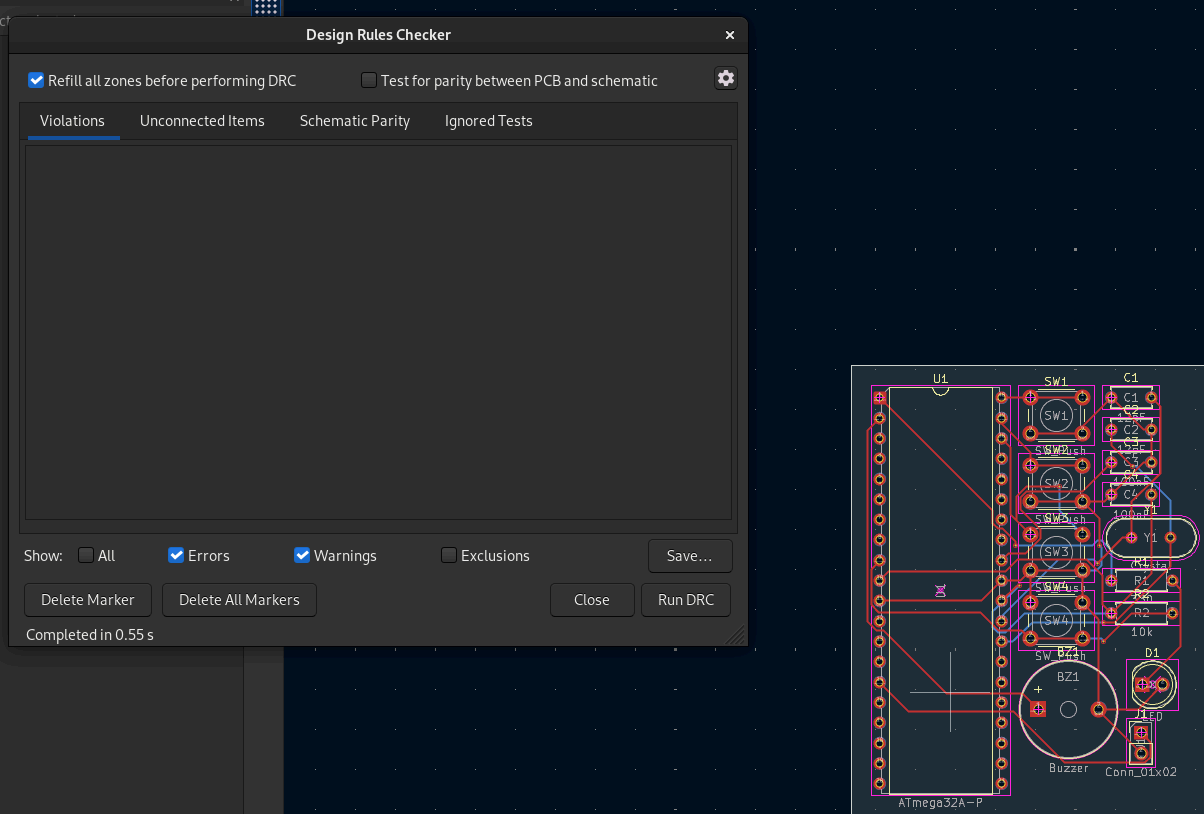
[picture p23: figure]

Figure 3.5 — DRC parameters and results confirming no violations

### 3.5 Output Generation

### 3.5.1 Gerber File Generation

Gerber files were generated from the completed PCB layout for manufacturing submission. Table 3.2 lists the files produced.

Layer | File Extension | Contents
Top copper | .GTL | Signal traces, pads, vias on component side
Bottom copper | .GBL | Bottom copper / ground plane
Top solder mask | .GTS | Solder mask openings on top layer
Bottom solder mask | .GBS | Solder mask openings on bottom layer
Top silkscreen | .GTO | Component outlines, reference designators, labels
Board outline | .GKO | PCB perimeter / edge cuts
Drill file | .TXT | NC drill coordinates for all holes and vias

Table 3.2 — Gerber file listing for PCB manufacturing

## Chapter Four

## Firmware Implementation

### 4.1 Overview and Development Environment

The firmware was developed using MPLAB for VS Code with the AVR-GCC toolchain, targeting the ATmega32 in bare-metal C. No RTOS or middleware libraries were used; all peripheral configuration, interrupt handling, and timing logic is implemented directly using the ATmega32 register set and AVR-libc headers (avr/io.h, avr/interrupt.h, avr/sleep.h, util/delay.h).

Parameter | Setting | Notes
MCU | ATmega32 | -mmcu=atmega32
CPU Frequency | 8 MHz | F_CPU = 8000000UL; internal RC oscillator
Optimisation | -Os | Size-optimised; ISR code is compact
Compiler | AVR-GCC via MPLAB | MPLAB for VS Code extension
Real hardware target | make | Uses TOSC async path and Power-Save sleep
SimulIDE target | make simulide | Defines -DSIMULIDE_MODE; uses CTC + Idle sleep

Table 4.1 — Firmware build environment

### 4.2 Firmware Architecture

The firmware follows a simple event-driven superloop architecture. The main loop polls buttons and checks for the g_time_updated flag set by the ISR; when the flag is set, the display is refreshed and the CPU returns to sleep. All time-critical operations (clock increment, alarm check, LED toggle, buzzer control) occur inside the ISR.

The high-level structure is:

main()
{
gpio_init(); | // configure PB0/PB1 outputs, PA0-2 inputs with
pull-ups
usart_init(); | // 9600 baud, 8N1, TX only on PD1
timer2_init(); | // async 32.768 kHz / 128 → 1-second overflow ISR
sei(); | // enable global interrupts
update_display(); // print initial state to terminal

while (1)
{
handle_buttons(); | // poll PA0, PA1, PA2 with debounce
if (g_time_updated) | // flag set by ISR each second
update_display(); | // print TIME/ALRM/MODE over USART
enter_sleep(); | // Power-Save; wakes on Timer2 overflow
}
}

### 4.3 Timer2 Asynchronous Configuration

The timer2_init() function implements the mandatory five-step procedure for enabling asynchronous Timer2 as specified in the ATmega32 datasheet:

1. Set AS2 bit in ASSR to connect Timer2 to the TOSC oscillator pins.
2. Clear TCNT2 to ensure a clean start.
3. Write TCCR2 with prescaler /128 (CS22 | CS20 = 0b101).
4. Wait until all ASSR busy flags clear (TCN2UB, OCR2UB, TCR2UB), confirming the async domain has latched the new register values. This step is mandatory; skipping it corrupts the timer configuration.
5. Enable the Timer2 overflow interrupt via TOIE2 in TIMSK.

The wait loop in step 4 is the most important synchronisation detail in the entire firmware. The asynchronous Timer2 register bus crosses two clock domains; any write that is not acknowledged by the async domain before the next write or before sleep entry will be silently discarded by the hardware.

### 4.4 Timekeeping and Alarm Logic (ISR)

The TIMER2_OVF_vect ISR fires every 1 second on real hardware. All of the following operations are performed inside the ISR to guarantee they execute exactly once per second with no possibility of drift:

- Increment g_seconds; if 60, reset to 0 and increment g_minutes.
- If g_minutes reaches 60, reset to 0 and increment g_hours.
- If g_hours reaches 24, reset to 0 (midnight rollover).
- If g_seconds is a multiple of WAKEUP_INTERVAL (10), toggle PB0 (wake-up LED) using XOR on PORTB.
- If the current time (g_hours:g_minutes:g_seconds) matches the alarm time and g_alarm_ringing is false, set g_alarm_ringing = true, load g_buzz_countdown with ALARM_BUZZ_DURATION (3 seconds), and assert PB1 (buzzer).
- If g_alarm_ringing is true and g_buzz_countdown reaches zero, clear g_alarm_ringing and deassert PB1.
- Set g_time_updated = true to signal the main loop that the display needs refreshing.

All variables modified inside the ISR are declared volatile. The main loop uses cli()/sei() pairs when reading multi-byte time values to prevent torn reads.

### 4.5 Button Handling and Debouncing

Buttons are polled in handle_buttons() on every main loop iteration. Three logical buttons are handled:

- PA0 (Reset): resets g_seconds, g_minutes, g_hours to zero; clears alarm state; returns mode to MODE_CLOCK.
- PA1 (Set Alarm): cycles the application mode through MODE_CLOCK → MODE_SET_ALARM_H → MODE_SET_ALARM_M → MODE_SET_ALARM_S → MODE_CLOCK.
- PA2 (Increment): increments the alarm field selected by the current mode (hours modulo 24, minutes/seconds modulo 60).

Software debouncing uses a read-delay-read strategy: the pin is sampled once; if LOW (pressed), a 20 ms delay is inserted; the pin is sampled again. Only if both reads agree is the press accepted. After a valid press, the code waits for the physical button release and adds a further 20 ms guard before returning.

### 4.6 Serial Output (USART)

The USART is configured for 9600 baud, 8N1, transmit-only mode. The baud rate register value is:

UBRR = (F_CPU / (16 × BAUD)) − 1 = (8,000,000 / (16 × 9600)) − 1 = 51

This gives a baud rate error of less than 0.2 %, which is well within the ±2 % tolerance of standard UART receivers. At 8 MHz with UBRR = 51, the actual baud rate is 9615.4 baud.

The update_display() function prints three lines each second using snprintf into a 32-byte stack buffer:

TIME: HH:MM:SS
ALRM: HH:MM:SS
MODE: LOW POWER (or SET ALARM HH / MM / SS) ---

### 4.7 Sleep Mode and Wake-Up Strategy

The enter_sleep() function selects SLEEP_MODE_PWR_SAVE and calls sleep_cpu() after enabling global interrupts. In Power-Save mode, the ATmega32 halts the CPU, stops all synchronous clocks, and disables all peripherals except the asynchronous Timer2 oscillator. The Timer2 overflow interrupt is the only event that can wake the CPU from this mode.

The wake-up sequence is: Timer2 overflows → interrupt fires → CPU wakes → ISR executes → ISR returns → sleep_disable() is called → main loop runs (button check + display update) → enter_sleep() called again → CPU sleeps until next second.

This means the CPU is active for only a few hundred microseconds per second, spending the remaining 99.9%+ of its time in the lowest available power state while Timer2 continues ticking from its independent crystal.

### 4.8 SimulIDE Fallback Mode (SIMULIDE_MODE)

SimulIDE does not simulate the external 32.768 kHz crystal oscillator on TOSC1/TOSC2. If the firmware compiled without the SIMULIDE_MODE flag is loaded in the simulator, Timer2 takes the asynchronous path (AS2 = 1) and attempts to wait for an oscillator that never starts; the busy flags in ASSR never clear, the timer never overflows, and when enter_sleep() is called with SLEEP_MODE_PWR_SAVE, the CPU halts permanently because the only possible wake source (Timer2 overflow) is also stalled.

The fallback, enabled by compiling with make simulide (-DSIMULIDE_MODE), configures Timer2 in CTC mode driven by the internal 8 MHz system clock:

Prescaler: /1024
OCR2 = 77
f_compare = 8,000,000 / (1024 × 78) ≈ 100.1 Hz ≈ 100 interrupts/second

The TIMER2_COMP_vect ISR accumulates ticks in g_tick_count; when 100 ticks have elapsed, the same timekeeping, alarm, LED, and buzzer logic from the real ISR executes. Because the synchronous system clock now drives Timer2, SLEEP_MODE_PWR_SAVE would stop that clock and stall the timer — so the fallback path uses SLEEP_MODE_IDLE instead, which halts only the CPU while keeping all timers and peripherals running.

All user-visible behaviour (serial output, button response, alarm, LED) is identical between the two paths. The only differences are the clock source driving Timer2 and the sleep depth.

### 4.9 GitHub Repository Reference

All project artefacts are maintained in a structured GitHub repository following the layout specified in the project brief:

ATmega32_Asynchronous_Timer2_Timekeeping/
├── README.md
├── firmware/
│ | ├── src/main.c
│ | ├── include/
│ | └── hex/
├── kicad/
│ | ├── schematic/
│ | ├── pcb/
│ | └── gerber/
├── simulide/
│ | ├── circuit/
│ | └── screenshots/
├── documentation/
│ | ├── block_diagram.png
│ | ├── flowchart.png

The firmware source is available at: [ GitHub Repository URL — insert link here ]

## Chapter Five

## Simulation and Testing

### 5.1 Simulation Environment

### 5.1.1 SimulIDE Setup

SimulIDE is a real-time electronic circuit simulator with AVR microcontroller support. Because SimulIDE does not model the external 32.768 kHz TOSC oscillator, the simulation uses the SIMULIDE_MODE firmware build (make simulide), which uses the internal 8 MHz clock to drive Timer2 in CTC mode at approximately 100 ticks per second, accumulating to one logical second in software. This limitation is documented in the firmware header and in Section 4.8; the KiCad schematic remains correct for the actual ATmega32 hardware target.

Parameter | Setting | Purpose
Simulator | SimulIDE v1.0+ | AVR circuit simulation and real-time debugging
MCU Model | mega32-2 (ATmega32) | Main controller simulation
MCU Clock Frequency | 8 MHz (must match F_CPU) | Required for correct USART baud rate calculation
Firmware | firmware_simulide.h ex | SIMULIDE_MODE build; CTC fallback for Timer2
Serial terminal | SerialTerm-8 | Receives USART output at 9600 baud, 8N1, ASCII
Sleep mode (sim) | SLEEP_MODE_IDL E | Keeps synchronous Timer2 clock running in sim

Table 5.1 — SimulIDE simulation environment configuration

### 5.1.2 Simulation Circuit Construction

The simulation circuit in SimulIDE includes the mega32-2 MCU component, a buzzer, an LED with 330 Ω series resistor, three toggle switches (PA0, PA1, PA2), a SerialTerm component connected to PD1 for serial output, and VCC/GND power rails. Note: the TOSC crystal circuit is present in the KiCad schematic but is not included in the SimulIDE circuit because the simulator cannot model it; the firmware fallback makes it unnecessary for simulation purposes.

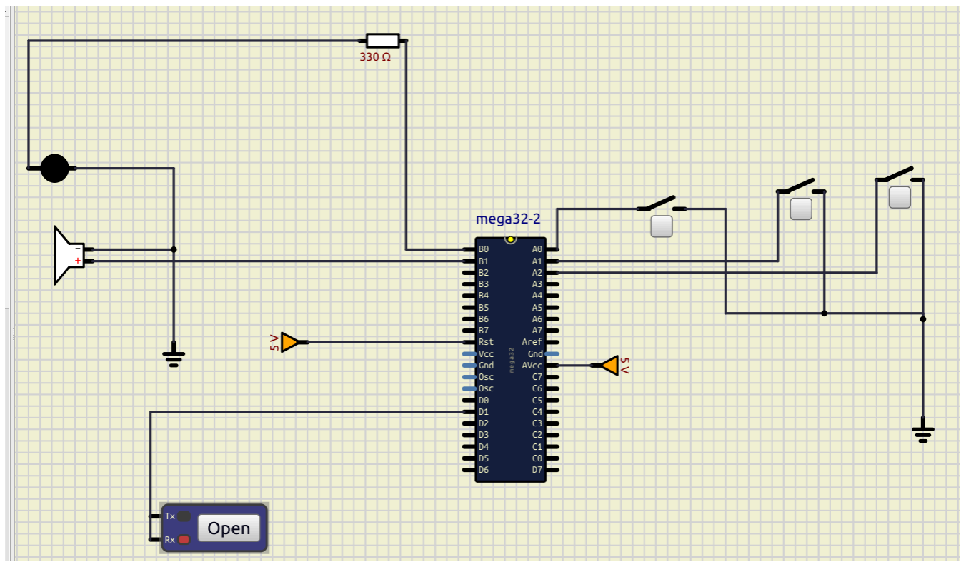
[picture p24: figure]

Figure 5.1 — Complete SimulIDE circuit with MCU, buzzer, LED, buttons, and serial terminal

### 5.2 Firmware Loading and Configuration

### 5.2.1 HEX File Loading and Clock Configuration

The compiled SimulIDE HEX file was loaded into the simulated ATmega32 using the following procedure:

6. Right-click the mega32-2 component in SimulIDE and select Properties.
7. In the Main tab, set Frequency to 8 and units to MHz. This step is critical: a
mismatch between the MCU clock setting and F_CPU causes UBRR to produce the wrong baud rate, resulting in garbled serial output.
8. In the Firmware field, browse to and select firmware/hex/firmware_simulide.hex.
9. Check "Reload hex at Simulation Start" for automatic firmware reloading.

10.Click the check mark to confirm and start the simulation.

Note: During initial development, the MCU clock was set to the default of 16 MHz while the firmware used F_CPU = 8 MHz, causing UBRR to be off by a factor of two and producing completely garbled serial output. Setting the clock to 8 MHz resolved this immediately, demonstrating that the baud rate register calculation and the simulator's clock frequency setting must always agree with the F_CPU macro in the firmware.

### 5.3 Test Cases and Results

All test cases specified in the project requirements were executed in SimulIDE. Results are documented below.

TC-01: System Start — Clock Initialises at 00:00:00

St ep | Action | Expected Result | Observed Result | Status
1 | Start simulation | Boot message printed, TIME: 00:00:00 | Boot banner and initial time printed correctly | ✓ PASS
2 | Observe serial terminal | MODE: LOW POWER displayed | MODE: LOW POWER confirmed | ✓ PASS

Table 5.2 — TC-01 Results


Figure 5.2 — Serial terminal showing initial boot message and 00:00:00 start state

TC-02: Timer2 Running — Seconds Increment Every Second

St ep | Action | Expected Result | Observed Result | Status
1 | Let simulation run | Seconds value increases each second | TIME updates 00:00:25 → 00:00:26 → ... confirmed | ✓ PASS
2 | Verify timing | One increment per simulation second | Increments align with simulation clock (1 s intervals) | ✓ PASS

Table 5.3 — TC-02 Results


Figure 5.3 — Serial terminal showing seconds incrementing correctly in real time

TC-03: Wake-Up LED Toggles at 10-Second Intervals

St ep | Action | Expected Result | Observed Result | Status
1 | Observe LED symbol at PB0 | LED toggles every 10 seconds | LED state changes at :00, :10, :20, :30... seconds | ✓ PASS
2 | Confirm via PORTB | PB0 XOR on every WAKEUP_INTERVA L multiple | Confirmed by LED indicator state in circuit | ✓ PASS

Table 5.4 — TC-03 Results


Figure 5.4 — LED indicator showing active state at a 10-second wake-up mark

TC-04: Alarm — Buzzer Activates at Programmed Time

St ep | Action | Expected Result | Observed Result | Status
1 | Press PA1 to enter SET ALARM HH mode | Serial shows MODE: SET ALARM HH | MODE field updated correctly | ✓ PASS
2 | Press PA2 to increment alarm hours | ALRM HH field increments | Alarm hours increment confirmed in ALRM display | ✓ PASS
3 | Press PA1 twice to reach SET ALARM SS, set seconds | Alarm field cycles correctly | All three fields (HH/MM/SS) settable and confirmed | ✓ PASS
4 | Press PA1 to exit to MODE_CLOCK; wait for alarm time | Buzzer activates for 3 seconds | Buzzer symbol activates; deactivates after 3 seconds | ✓ PASS

Table 5.5 — TC-04 Results


Figure 5.5 — Serial terminal in SET ALARM mode and buzzer active at alarm time

TC-05: Reset Button — Clock Returns to 00:00:00

St ep | Action | Expected Result | Observed Result | Status
1 | Press PA0 while clock is running | TIME resets to 00:00:00; MODE_CLOCK restored | TIME RESET TO 00:00:00 printed; time restarts | ✓ PASS
2 | Confirm alarm state | Alarm ringing cleared; buzzer stops if active | Buzzer and alarm state cleared on reset | ✓ PASS

Table 5.6 — TC-05 Results


Figure 5.6 — Serial terminal showing TIME RESET TO 00:00:00 message

TC-06: Sleep Mode Behaviour (Documented Limitation)

St ep | Observation | Explanation | Status
1 | Warning: "AVR SLEEP instruction not Fully implemented" in SimulIDE console | SimulIDE does not fully model Power-Save or Idle sleep modes | Docume nted
2 | In SIMULIDE_MODE: SLEEP_MODE_IDL E is used instead of SLEEP_MODE_PW R_SAVE | IDLE keeps the synchronous clock running so Timer2 CTC continues ticking | Correct per design
3 | On real hardware: SLEEP_MODE_PW R_SAVE would be used; async Timer2 continues from its own crystal while CPU is halted | Power-Save is the optimal mode for async Timer2 timekeeping; this is correct for the hardware design | Correct per design

Table 5.7 — TC-06: Sleep mode documentation

## Chapter Six

## Conclusion

### 6.1 Project Summary

This project successfully designed and implemented a low-power real-time timekeeping system on the ATmega32 microcontroller, centred on the asynchronous operation of Timer/Counter2 driven by a 32.768 kHz external watch crystal. The system achieved all required behaviours: accurate one-second timekeeping via Timer2 overflow interrupts, a
ten-second | wake-up | LED | heartbeat, | a | user-programmable | buzzer | alarm,
software-debounced button input for clock reset and alarm configuration, and USART serial output displaying real-time clock state at 9600 baud.

The complete design was documented through a KiCad schematic with all required net labels and crystal placement, a PCB layout following the oscillator design rules specified in the project brief, and firmware verified in SimulIDE using a documented internal-clock fallback that transparently substitutes for the TOSC oscillator the simulator cannot model. The key technical challenge encountered — that Power-Save sleep mode halts the synchronous clock domain and therefore stalls a synchronously-clocked Timer2 fallback — was identified, explained, and resolved by switching to SLEEP_MODE_IDLE in the simulator path.

### 6.2 Learning Outcomes and Discussion

This project provided direct experience with several important embedded systems concepts:

- Asynchronous peripheral operation — understanding that Timer2's ability to run from a separate clock domain, decoupled from the main system clock, is a hardware feature unique to this peripheral among the ATmega32's three timers, and that this decoupling is the enabler of proper low-power timekeeping.
- Clock domain crossing — the mandatory register synchronisation wait loop in timer2_init() demonstrated that writing registers to hardware in a different clock domain requires explicit busy-wait acknowledgement; skipping this step silently corrupts the configuration.
- Power-Save sleep mode mechanics — learning that SLEEP_MODE_PWR_SAVE specifically preserves the asynchronous Timer2 oscillator domain while stopping everything else. Using it with a synchronously-clocked Timer2 is a silent correctness bug: the timer stops, the wake-up source disappears, and the CPU parks indefinitely.
- USART baud rate sensitivity — discovering that a clock frequency mismatch between the firmware (F_CPU macro) and the simulator MCU configuration directly corrupts serial output, and that the fix is precise agreement between these two values.
- SimulIDE limitations and workarounds — developing the two-path firmware (real hardware vs. simulator fallback) as a template for working around simulator hardware gaps while keeping all application logic identical and testable.

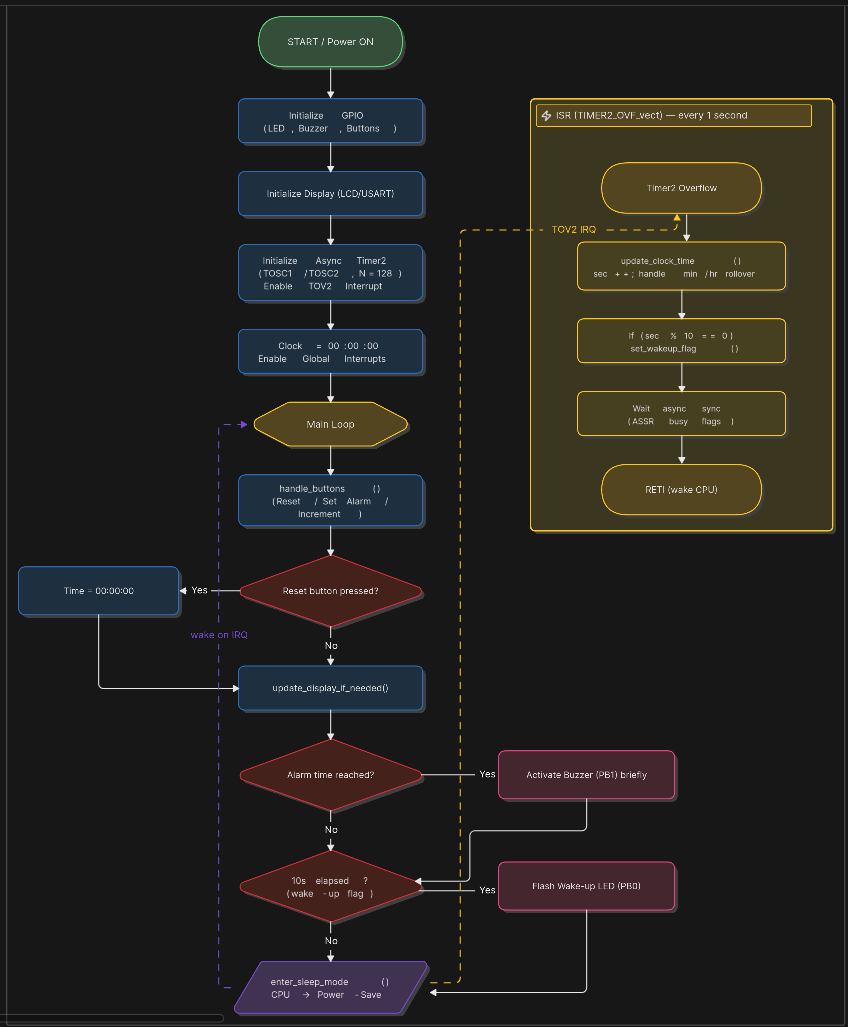
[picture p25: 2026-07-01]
documentation/Screenshot From 2026-07-01 10-00-53.png

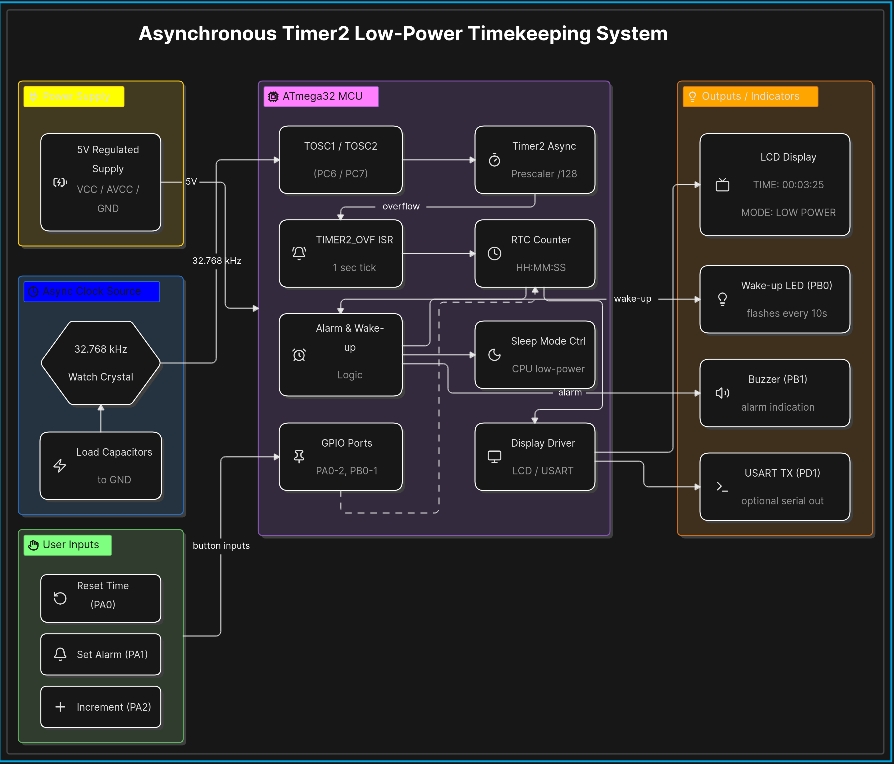
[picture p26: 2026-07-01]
documentation/Screenshot From 2026-07-01 08-00-54.png

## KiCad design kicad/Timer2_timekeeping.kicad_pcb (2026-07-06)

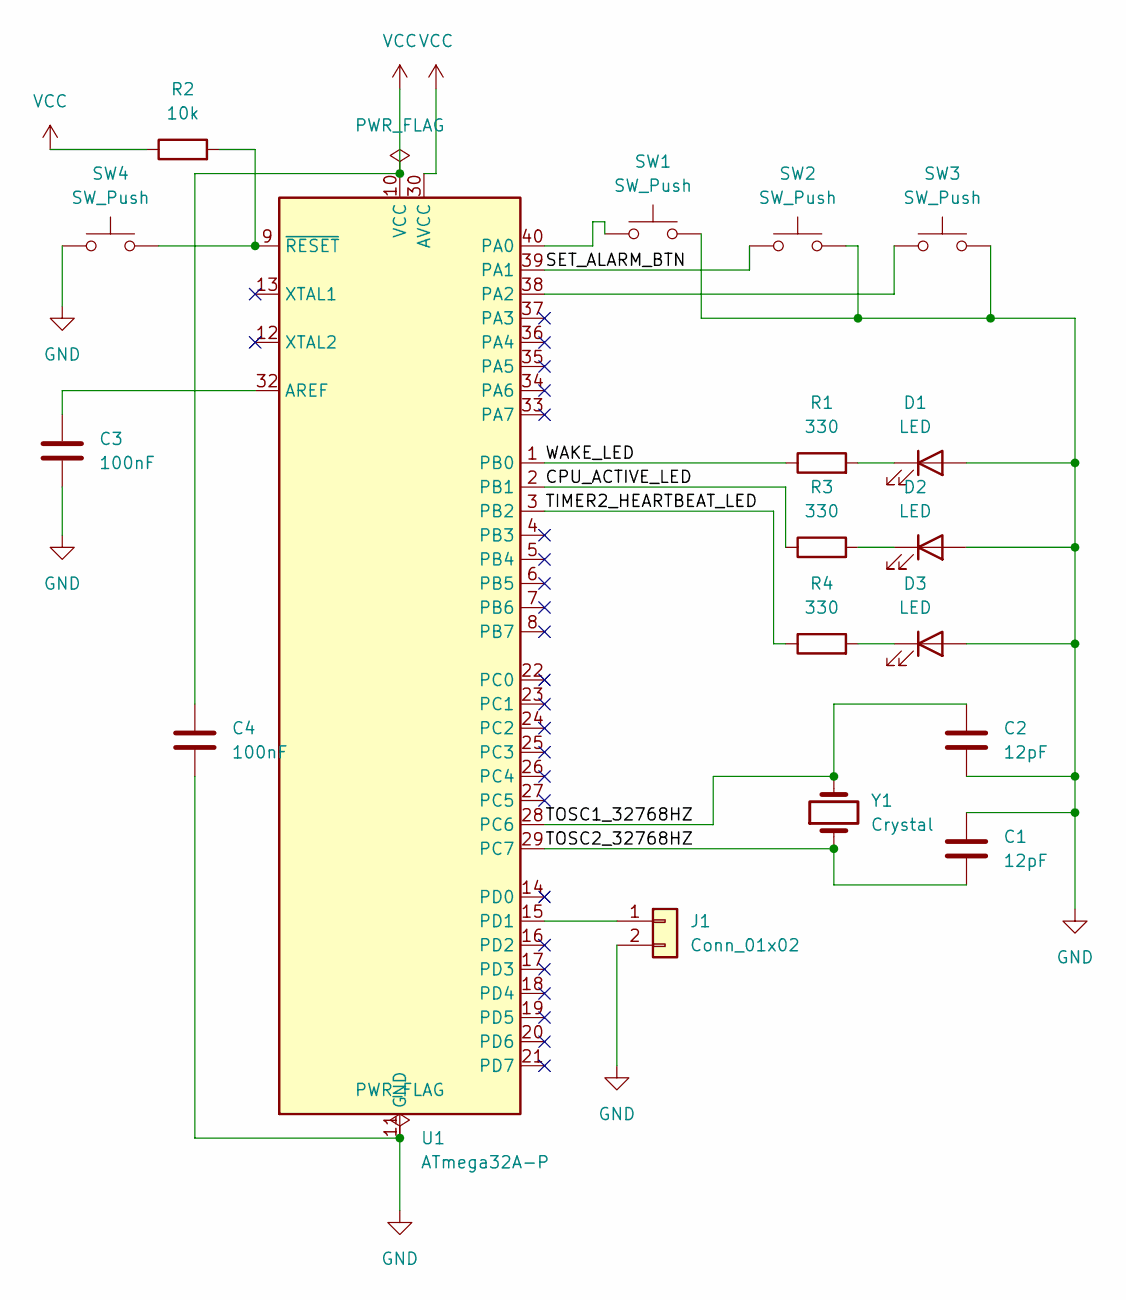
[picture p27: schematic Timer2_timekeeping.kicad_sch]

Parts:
C1, C2: 12pF; C_Disc_D5.0mm_W2.5mm_P5.00mm
C3, C4: 100nF; C_Disc_D5.0mm_W2.5mm_P5.00mm
D1, D2, D3: LED; LED_D5.0mm
J1: Conn_01x02; PinHeader_1x02_P2.54mm_Vertical
R1, R3, R4: 330; R_Axial_DIN0207_L6.3mm_D2.5mm_P7.62mm_Horizontal
R2: 10k; R_Axial_DIN0207_L6.3mm_D2.5mm_P7.62mm_Horizontal
SW1, SW2, SW3, SW4: SW_Push; SW_PUSH_6mm
U1: ATmega32A-P; DIP-40_W15.24mm
Y1: Crystal; Crystal_HC49-4H_Vertical

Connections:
/CPU_ACTIVE_LED: R3.1, U1.2 (PB1)
/SET_ALARM_BTN: SW2.1, U1.39 (PA1)
/TIMER2_HEARTBEAT_LED: R4.1, U1.3 (PB2)
/TOSC1_32768HZ: C2.1, U1.28 (PC6), Y1.2
/TOSC2_32768HZ: C1.2, U1.29 (PC7), Y1.1
/WAKE_LED: R1.1, U1.1 (PB0)
GND: C1.1, C2.2, C3.2, C4.1, D1.2 (A), D2.2 (A), D3.2 (A), J1.2, SW1.2, SW2.2, SW3.2, SW4.1, U1.11 (GND), U1.31 (GND)
unnamed: D1.1 (K), R1.2
unnamed: D2.1 (K), R3.2
unnamed: D3.1 (K), R4.2
unnamed: J1.1, U1.15 (PD1)
unnamed: C3.1, U1.32 (AREF)
unnamed: SW1.1, U1.40 (PA0)
unnamed: SW3.1, U1.38 (PA2)
unnamed: R2.2, SW4.2, U1.9 (~RESET)
VCC: C4.2, R2.1, U1.10 (VCC), U1.30 (AVCC)

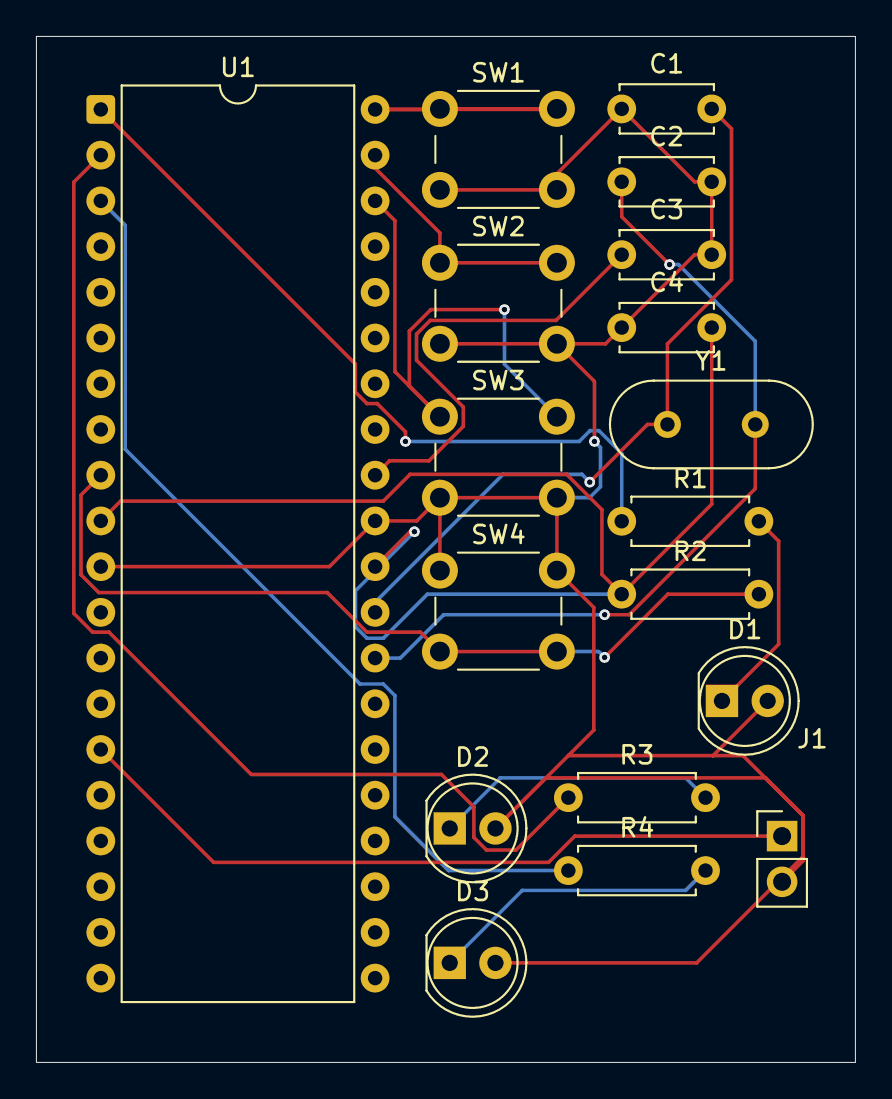
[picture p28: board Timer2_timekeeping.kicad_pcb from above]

Board: 2 copper layers, 45.5 x 57.0 mm, 18 parts (0 on the bottom side), 16 nets.

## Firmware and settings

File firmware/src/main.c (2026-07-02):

#define F_CPU 8000000UL

#include <avr/interrupt.h>
#include <avr/io.h>
#include <avr/sleep.h>
#include <stdbool.h>
#include <stdio.h>
#include <string.h>
#include <util/delay.h>

// configs
#define WAKE_LED_PIN PB0
#define BUZZER_PIN PB1
#define BTN_RESET PA0
#define BTN_SET_ALARM PA1
#define BTN_INCREMENT PA2

#define ALARM_BUZZ_DURATION 3

#define WAKEUP_INTERVAL 10

#define BAUD 9600
#define UBRR_VALUE ((F_CPU / (16UL * BAUD)) - 1) // = 51 at 8 MHz 

volatile uint8_t g_seconds = 0;
volatile uint8_t g_minutes = 0;
volatile uint8_t g_hours = 0;

volatile uint8_t g_alarm_seconds = 0;
volatile uint8_t g_alarm_minutes = 0;
volatile uint8_t g_alarm_hours = 0;

volatile bool g_time_updated = false; 
volatile bool g_alarm_ringing = false;
volatile uint8_t g_buzz_countdown = 0; 

#ifdef SIMULIDE_MODE
volatile uint8_t g_tick_count = 0;
#define TICKS_PER_SECOND 100 
#endif

typedef enum
{
  MODE_CLOCK,       
  MODE_SET_ALARM_H, 
  MODE_SET_ALARM_M, 
  MODE_SET_ALARM_S  
} AppMode;

volatile AppMode g_mode = MODE_CLOCK;


static void usart_init(void)
{
  UBRRH = (uint8_t)(UBRR_VALUE >> 8);
  UBRRL = (uint8_t)(UBRR_VALUE);
  UCSRB = (1 << TXEN);                                
  UCSRC = (1 << URSEL) | (1 << UCSZ1) | (1 << UCSZ0); 
}

static void usart_putchar(char c)
{
  while (!(UCSRA & (1 << UDRE)))
    ;
  UDR = c;
}

static void usart_print(const char *str)
{
  while (*str)
    usart_putchar(*str++);
}

static void usart_print_time(uint8_t h, uint8_t m, uint8_t s,
                             const char *label)
{
  char buf[32];
  snprintf(buf, sizeof(buf), "%s %02u:%02u:%02u\r\n", label, h, m, s);
  usart_print(buf);
}

static void gpio_init(void)
{
  DDRB |= (1 << WAKE_LED_PIN) | (1 << BUZZER_PIN) | (1 << PB2) | (1 << PB3);
  PORTB &= ~((1 << WAKE_LED_PIN) | (1 << BUZZER_PIN) | (1 << PB2) | (1 << PB3)); 

  DDRA &= ~((1 << BTN_RESET) | (1 << BTN_SET_ALARM) | (1 << BTN_INCREMENT));
  PORTA |= (1 << BTN_RESET) | (1 << BTN_SET_ALARM) | (1 << BTN_INCREMENT);
}

static void timer2_init(void)
{
#ifndef SIMULIDE_MODE
  //Async clock source
  ASSR |= (1 << AS2);

  TCNT2 = 0;

  TCCR2 = (1 << CS22) | (1 << CS20);

  while (ASSR & ((1 << TCN2UB) | (1 << OCR2UB) | (1 << TCR2UB)))
    ;
  TIMSK |= (1 << TOIE2);

#else
  TCCR2 = (1 << WGM21)                               
          | (1 << CS22) | (1 << CS21) | (1 << CS20); 
  OCR2 = 77;                                         
  TIMSK |= (1 << OCIE2);                            
#endif
}

#ifndef SIMULIDE_MODE

ISR(TIMER2_OVF_vect)
{
  g_seconds++;
  if (g_seconds >= 60)
  {
    g_seconds = 0;
    g_minutes++;
  }
  if (g_minutes >= 60)
  {
    g_minutes = 0;
    g_hours++;
  }
  if (g_hours >= 24)
  {
    g_hours = 0;
  }

  if (g_seconds % WAKEUP_INTERVAL == 0)
    PORTB ^= (1 << WAKE_LED_PIN);

  if (!g_alarm_ringing && g_hours == g_alarm_hours &&
      g_minutes == g_alarm_minutes && g_seconds == g_alarm_seconds)
  {
    g_alarm_ringing = true;
    g_buzz_countdown = ALARM_BUZZ_DURATION;
    PORTB |= (1 << BUZZER_PIN);
  }


  if (g_alarm_ringing)
  {
    if (g_buzz_countdown > 0)
    {
      g_buzz_countdown--;
    }
    else
    {
      g_alarm_ringing = false;
      PORTB &= ~(1 << BUZZER_PIN);
    }
  }

  PORTB ^= (1 << PB3);
  g_time_updated = true;
}

#else 
ISR(TIMER2_COMP_vect)
{
  g_tick_count++;
  if (g_tick_count < TICKS_PER_SECOND)
    return; 
  g_tick_count = 0;

  
  g_seconds++;
  if (g_seconds >= 60)
  {
    g_seconds = 0;
    g_minutes++;
  }
  if (g_minutes >= 60)
  {
    g_minutes = 0;
    g_hours++;
  }
  if (g_hours >= 24)
  {
    g_hours = 0;
  }

  if (g_seconds % WAKEUP_INTERVAL == 0)
    PORTB ^= (1 << WAKE_LED_PIN);

  if (!g_alarm_ringing && g_hours == g_alarm_hours &&
      g_minutes == g_alarm_minutes && g_seconds == g_alarm_seconds)
  {
    g_alarm_ringing = true;
    g_buzz_countdown = ALARM_BUZZ_DURATION;
    PORTB |= (1 << BUZZER_PIN);
  }

  if (g_alarm_ringing)
  {
    if (g_buzz_countdown > 0)
    {
      g_buzz_countdown--;
    }
    else
    {
      g_alarm_ringing = false;
      PORTB &= ~(1 << BUZZER_PIN);
    }
  }

  PORTB ^= (1 << PB3);
  g_time_updated = true;
}

#endif 

static bool button_pressed(uint8_t pin)
{
  if (!(PINA & (1 << pin)))
  {                           
    _delay_ms(20);            
    if (!(PINA & (1 << pin))) 
      return true;
  }
  return false;
}

static void handle_buttons(void)
{
  if (button_pressed(BTN_RESET))
  {
    cli(); 
    g_seconds = 0;
    g_minutes = 0;
    g_hours = 0;
    g_alarm_ringing = false;
    g_buzz_countdown = 0;
    PORTB &= ~((1 << WAKE_LED_PIN) | (1 << BUZZER_PIN));
    g_mode = MODE_CLOCK;
    sei();
    usart_print("TIME RESET TO 00:00:00\r\n");
    while (!(PINA & (1 << BTN_RESET)))
      ;
    _delay_ms(20);
    return;
  }

  if (button_pressed(BTN_SET_ALARM))
  {
    switch (g_mode)
    {
    case MODE_CLOCK:
      g_mode = MODE_SET_ALARM_H;
      break;
    case MODE_SET_ALARM_H:
      g_mode = MODE_SET_ALARM_M;
      break;
    case MODE_SET_ALARM_M:
      g_mode = MODE_SET_ALARM_S;
      break;
    case MODE_SET_ALARM_S:
      g_mode = MODE_CLOCK;
      break;
    }
    while (!(PINA & (1 << BTN_SET_ALARM)))
      ;
    _delay_ms(20);
  }

  if (button_pressed(BTN_INCREMENT))
  {
    switch (g_mode)
    {
    case MODE_CLOCK:
      break; 
    case MODE_SET_ALARM_H:
      g_alarm_hours = (g_alarm_hours + 1) % 24;
      break;
    case MODE_SET_ALARM_M:
      g_alarm_minutes = (g_alarm_minutes + 1) % 60;
      break;
    case MODE_SET_ALARM_S:
      g_alarm_seconds = (g_alarm_seconds + 1) % 60;
      break;
    }
    while (!(PINA & (1 << BTN_INCREMENT)))
      ;
    _delay_ms(20);
  }
}

static void update_display(void)
{
  cli();
  uint8_t h = g_hours, m = g_minutes, s = g_seconds;
  uint8_t ah = g_alarm_hours, am = g_alarm_minutes, as_ = g_alarm_seconds;
  AppMode mode = g_mode;
  g_time_updated = false;
  sei();

  usart_print_time(h, m, s, "TIME: ");

  usart_print_time(ah, am, as_, "ALRM: ");

  switch (mode)
  {
  case MODE_CLOCK:
    usart_print("MODE: LOW POWER\r\n");
    break;
  case MODE_SET_ALARM_H:
    usart_print("MODE: SET ALARM HH\r\n");
    break;
  case MODE_SET_ALARM_M:
    usart_print("MODE: SET ALARM MM\r\n");
    break;
  case MODE_SET_ALARM_S:
    usart_print("MODE: SET ALARM SS\r\n");
    break;
  }
  usart_print("---\r\n");
}

static void enter_sleep(void)
{
#ifdef SIMULIDE_MODE
  return; 
#else
  set_sleep_mode(SLEEP_MODE_PWR_SAVE);
  sleep_enable();
  sei();
  sleep_cpu();
  sleep_disable();
#endif
}

int main(void)
{
  gpio_init();
  usart_init();
  timer2_init();
  sei(); 

  usart_print("\r\n== ATmega32 Async Timer2 Timekeeping ==\r\n");
#ifdef SIMULIDE_MODE
  usart_print("(SimulIDE mode: internal clock fallback)\r\n");
#else
  usart_print("(Hardware mode: 32.768 kHz TOSC crystal)\r\n");
#endif
  usart_print("Buttons: PA0=Reset  PA1=SetAlarm  PA2=Increment\r\n");
  usart_print("---\r\n");

  update_display();

  while (1)
  {
    PORTB |= (1 << PB2);
    handle_buttons();

    if (g_time_updated)
      update_display();
    PORTB &= ~(1 << PB2);
    enter_sleep();
  }

  return 0;
}

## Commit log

2026-07-01 Asynchronous Timer2 project
    [Timer2_timekeeping-B_Cu.gbr, Timer2_timekeeping-B_Mask.gbr, Timer2_timekeeping-B_Paste.gbr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]
2026-07-06 small pcb update
    [Timer2_timekeeping.kicad_pcb, Timer2_timekeeping.kicad_sch]
2026-07-06 updated gerber and drill files
    [Timer2_timekeeping-B_Cu.gbr, Timer2_timekeeping-B_Mask.gbr, Timer2_timekeeping-B_Paste.gbr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]
